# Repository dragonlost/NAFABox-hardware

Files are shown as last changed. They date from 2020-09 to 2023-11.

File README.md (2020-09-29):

# NAFABox-hardware   

__Version francaise :__    

Le but de ce projet, qui est née fin 2018, est de pouvoir proposer à tous des cartes électroniques plugables sur une carte Raspberry Pi (ou carte avec connecteur 40pins compatible) dédié aux astronomes amateurs.

Après 2 prototypes réalisés mais pas assez fonctionnel et compact à mon goût, l'idée fut de partir sur une achitecture modulaire stackable sur un Raspberry Pi.

Grâce à Kicad et ses possibilités 3D nous avons pu mener à bien ce projet.

Malheuresement, n'ayant pas de formation en électronique/design de PCB ou en réalisation mécanique, les réalisatons ne sont pas parfaite et ne respecte surement pas totalement les normes et caractéristique du domaine.

Ce projet est Open Source et donc j'invite toutes personnes voulant contribuer à sa réalisation à proposer un Pull Request/Issue ou à me contacter via mon Pseudo (le même que sur Github) sur Webastro ou sur le Discord : "Astro - FR".

__Attention :__ La plupart des modèles 3D présent dans de dossier __lib__ de chaque PCB sont issue du site https://grabcad.com/ et ne sont pas forcement tous OpenSource. Merci de respecter leurs droits de diffusion.

## Les différentes cartes :

Tout les schémas électronique sont disponible dans la Doc : https://github.com/dragonlost/NAFABox-hardware/tree/master/Doc/schema_pdf

### La carte de base :
(base_hat)     
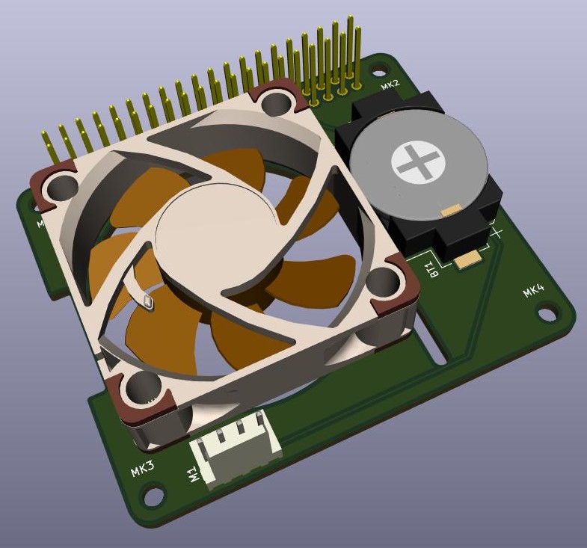
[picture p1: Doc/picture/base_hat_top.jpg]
base_hat_top
 
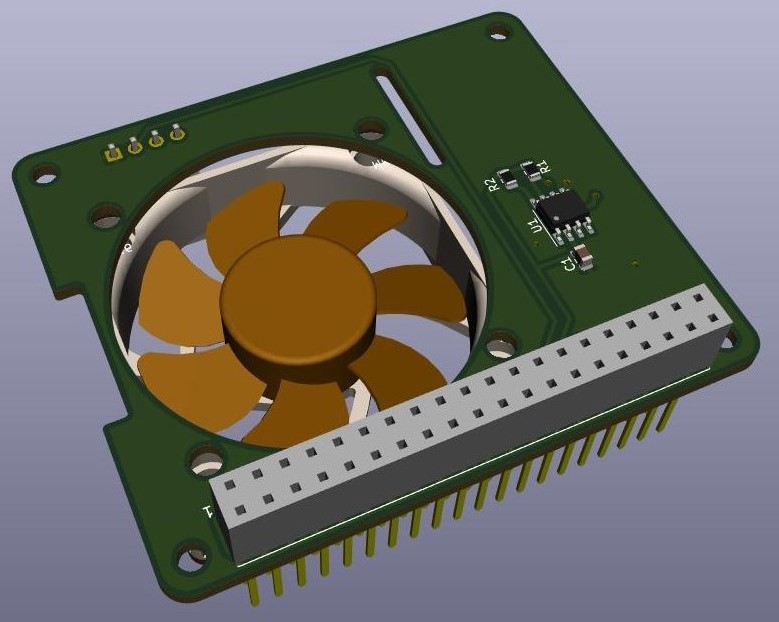
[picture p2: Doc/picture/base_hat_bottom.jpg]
base_hat_bottom
 

Cette carte contient principalement 2 parties : 
- un composant DS3231 en I2C afin de pouvoir obtenir une base de temps permanente pour le Raspberry Pi ainsi qu'un logement de pile pour un CR2032 remplacable
- un connecteur et emplacement pour un ventillateur de 30x30mm controlé en PWM par le Raspberry PI.  

### La carte d'alimentation :
(alim_hat)    
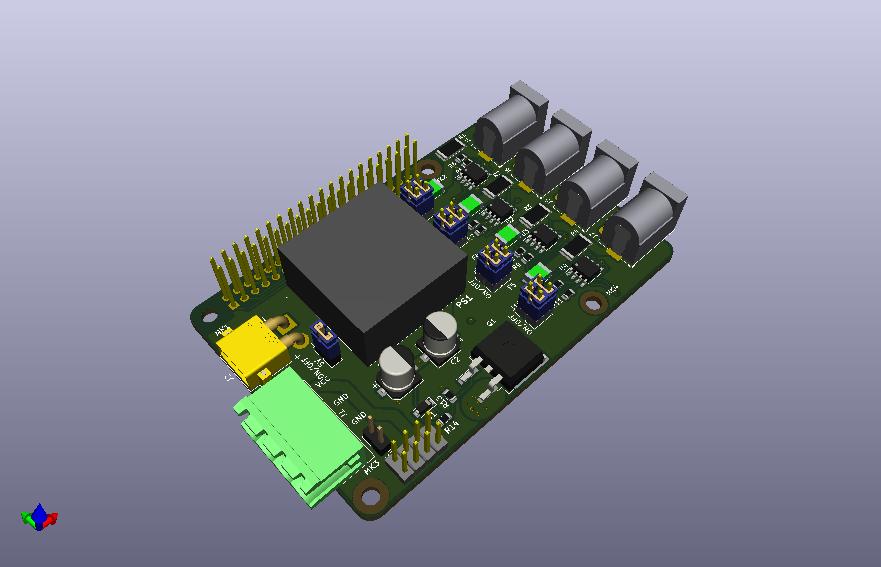
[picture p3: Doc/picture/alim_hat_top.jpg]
alim_hat_top
 
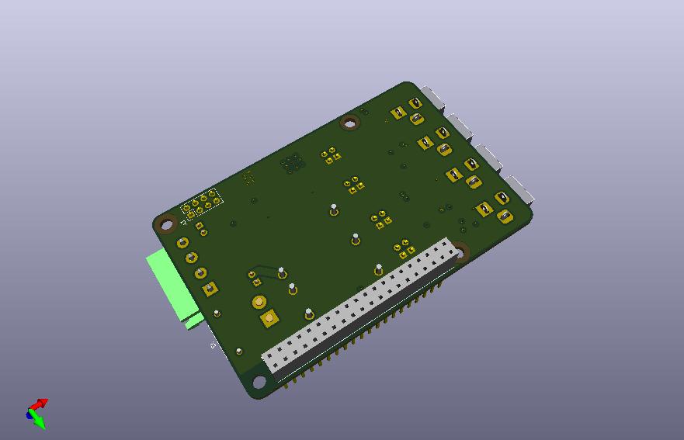
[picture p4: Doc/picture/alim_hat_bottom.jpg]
alim_hat_bottom
 

Elle contient :
- Une entrée d'alimentation Jack DC protégé contre l'inversion de courant.
- 4 sorties :
	- protégées par des fusibles rearmable PPTC ( polyswitch/polyfuse) de 5A
	- mesurer en courant et tension à l'aide d'INA219 en I2C ( un par sortie)
	- de tension identique à la tension d'entrée
- un connecteur 8 broches avec la tension d'entré (x2) et la masse (x4) ainsi qu'une autre tension (VCC) entrée via le bornier prevue à cette effet
- un convertisseur DC-DC stepdown PDQE15-Q24-S5-D isolé ( désactivable) pouvant délivré 3A en 5V relié au pins 5v du Raspberry Pi.
- de pin permettant de couper/connecter chaque sortie via un Jumper ou des interupteurs externe ou via la carte relais.

### La carte Relais/ Focuser
(relais_hat)
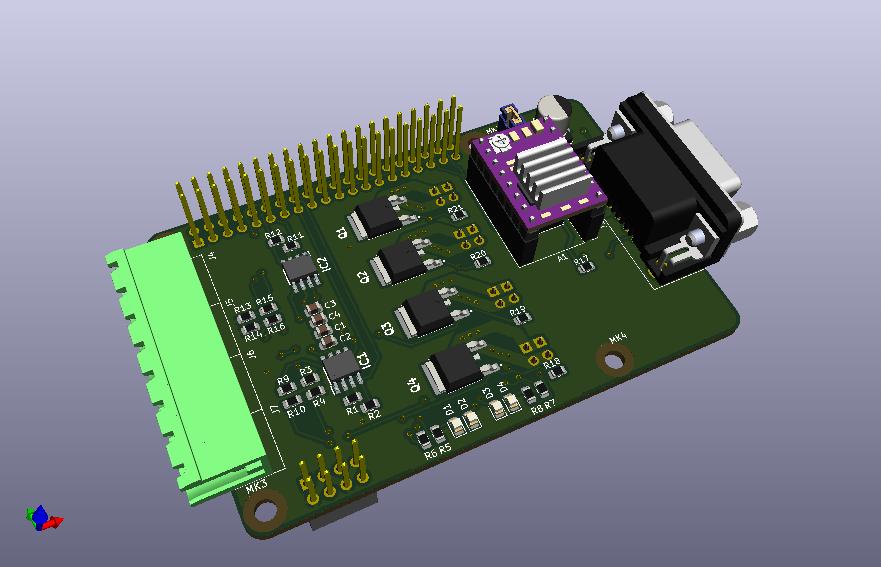
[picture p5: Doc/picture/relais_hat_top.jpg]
relais_hat_top
 
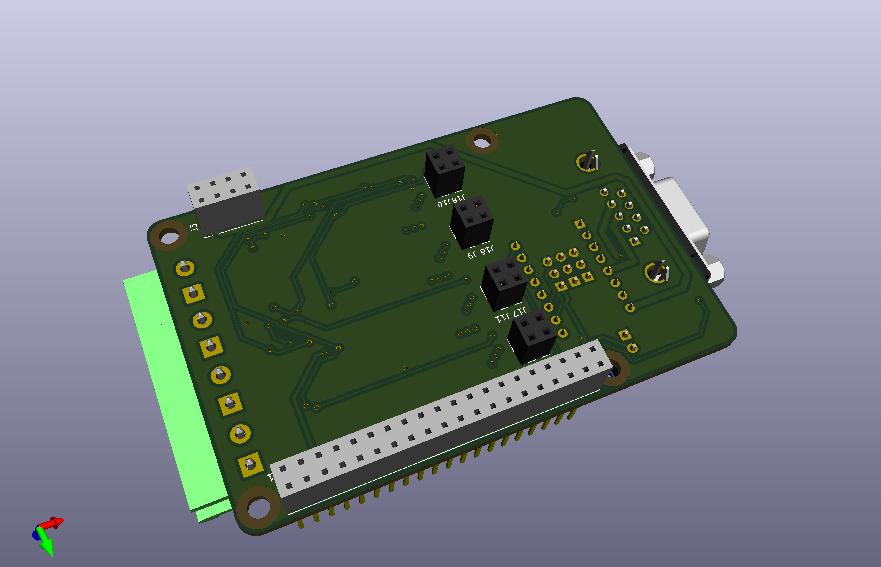
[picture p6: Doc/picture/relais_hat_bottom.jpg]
relais_hat_bottom
 

Elle contient :
- Un système de 4 relais :
	- 4 relais piloté via les GPIO de carte Raspberry PI (GPIO 17, 18, 22 et 23)
	- 4 leds indiquant l'état des relais (dans le même ordre D1, D2, D3, D4)
	- 4 sorties par pins plugable sur la carte d'alimentation pour piloter les 4 sorties.
	- 4 bornier pour piloter un système externe
- un connecteur 8 broches avec la tension d'entrée (x2) et la masse (x4) ainsi qu'une autre tension (VCC) entrée via le bornier de la carte d'alimentation
- Un système pour piloter un moteur pas à pas afin de réaliser la mise au point.
	- un emplacemnt pour driveur moteur au format pololu
	- un connecteur DB9 au format RoboFocus (A1=1, A2=2, B1=3, B2=4, GND=5)
	- un système de 3 jumper afin de piloter l'état des pins (libre, 3.3v, GND)
	- pilotage via les GPIO (STEP=GPIO25, DIR=GPIO27, SLP=GPIO24)
	- l'alimentation 12v via la connecteur 8 pins.

### La carte Resistance chauffante et GPS
(res_hat)
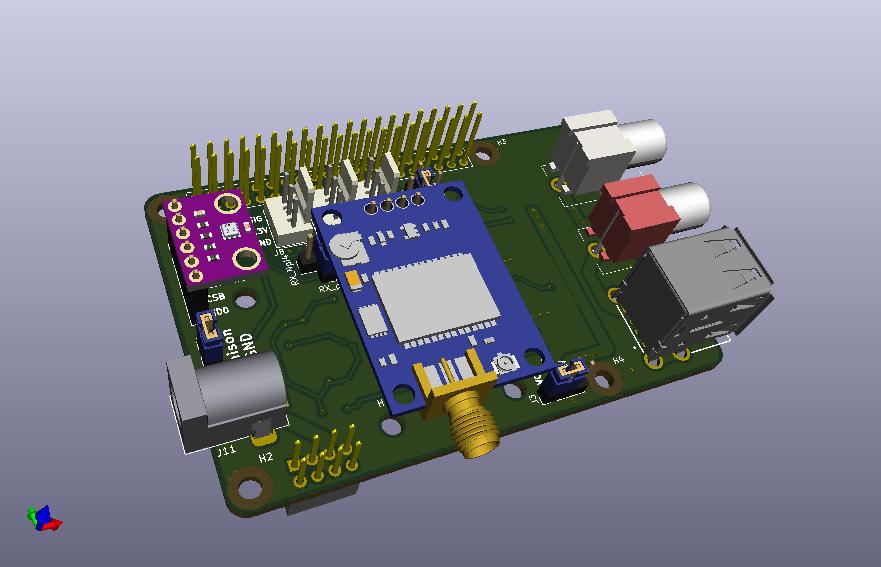
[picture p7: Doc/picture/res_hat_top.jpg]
res_hat_top
 
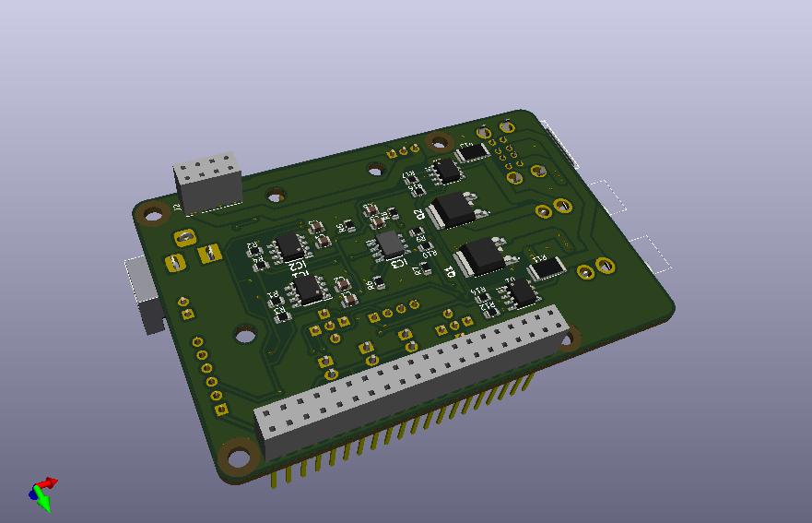
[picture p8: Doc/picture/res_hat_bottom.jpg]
res_hat_bottom
 

Elle contient :
- un connecteur 8 broches avec la tension d'entrée (x2) et la masse (x4) ainsi qu'une autre tension (VCC) entrée via le bornier de la carte d'alimentation
- un connecteur 4 pins pour connecteur une carte GPS UART (3.3v-RX-TX-GND) :
	- 2 trous de fixation mécanique
	- 2 systèmes de jumper afin d'inverser le TX/RX ou sélectioner d'autre pin TX-RX pour la carte Nanopi-M4 
- une entrée Jack DC connecter a la tension VCC.
- un système de résistance chauffante piloter par I2C :
	- 2 résistance possible, connectable via 2x USB (résistance en 5V par exemple) ou via 2x RCA.
	- chaque sortie est mesurée en tension et courant via des INA219 comme la carte d'alimentation
	- un connecteur pour une carte BME280 en i2C afin de calculer le point de rosé via la température et l'humidité local.
	- 2 connecteurs pour 2 capteurs D18B20 1wire (pin7 du RPI) afin de mesurer la température des résistances.
	- Chaque résistance est pilotable en puissance via 2 mofset FDD844L-F085
	- Il est posible via un jumper de sélectionner la tension d'alimentation des résistances entre l'entrée Jack de la carte d'alimentation (nomé: 12V) et l'entrée jack de la carte résistance ou du bornier de la carte d'alimentation (nomé: VCC)

## Le Boitier :

Le boitier destiné à accueillir les différentes cartes a été concue comme les cartes afin d'être modulaire. Chaque carte possède donc sa propre pièce.    
Les modèles 3D des cartes sont aussi disponibles afin de permettre à chacun de réaliser son propre boitier.

Elle a été aussi concu afin d'être facilement imprimable sur des imprimantes de capacité d'impression de 20x20x20.    

Les pièces ont été dessiné sous CATIA par __SUPAII__ puis publié en format STEP afin que chacun puisse les modifiés/convertir avec n'importe quel logiciel de CAO.    

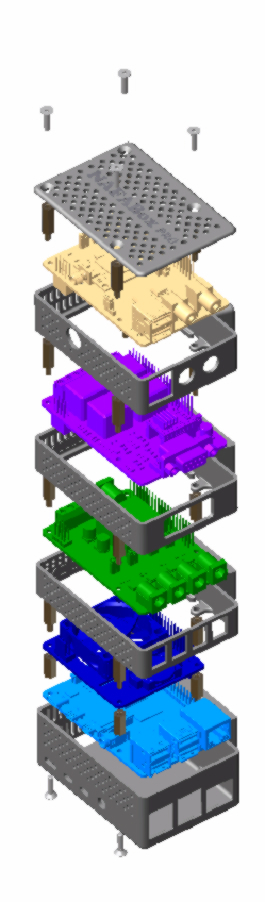
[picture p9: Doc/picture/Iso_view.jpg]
Iso_view

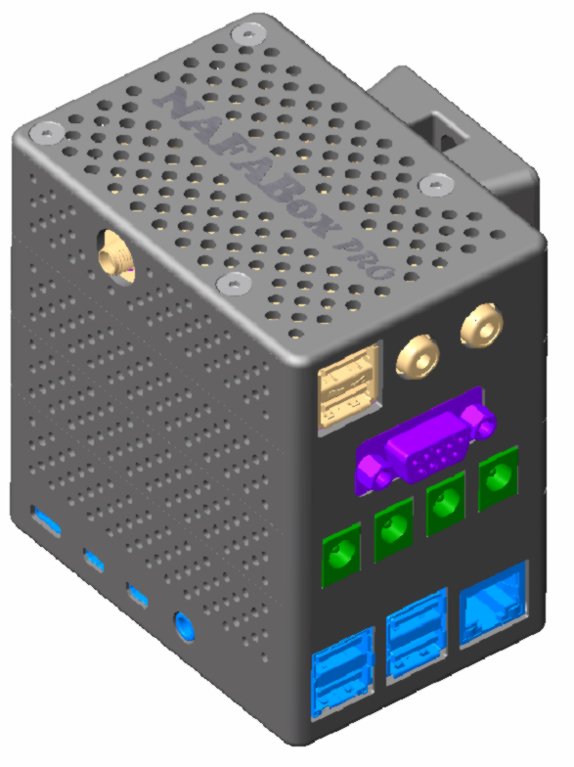
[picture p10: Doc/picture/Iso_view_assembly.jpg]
Iso_view_assembly


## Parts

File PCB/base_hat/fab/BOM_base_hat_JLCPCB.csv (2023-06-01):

Comment | Designator | Footprint | LCSC Part Number
RTC | U1 | SOIC-8 | C107410
10k ohm | R2,R1 | 805 | C17414
1 uF | C1 | 805 | C28323

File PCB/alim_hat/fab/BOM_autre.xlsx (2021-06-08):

BOM des composants non cablés par JLCPCB
ref-pcb | number | commentaire | fabriquant | ref fab | ref mouser | lien
PS1-15W | 0 | DC-DC for 5V | TDK-Lambda | CCG152405S | 967-CCG152405S | https://www.mouser.fr/ProductDetail/TDK-Lambda/CCG152405S?qs=LuYMPh7GGMTuVM%2FVwXHZSQ%3D%3D
PS1-15W-bis | 0 | DC-DC for 5V | TRACO Power | THL 15-2411WI | 495-THL15-2411WI | https://www.mouser.fr/ProductDetail/TRACO-Power/THL-15-2411WI?qs=vLWxofP3U2zTxW0y6%2FAPOg%3D%3D
PS1-20W | 0 | DC-DC for 5V | CUI Inc | PDQE20-Q24-S5-D | 490-PDQE20-Q24-S5-D | https://www.mouser.fr/ProductDetail/CUI-Inc/PDQE20-Q24-S5-D?qs=T3oQrply3y%2FtCzjhZ6U7qw%3D%3D
PS1-20W-bis | 0 | DC-DC for 5V | TRACO Power | THN 20-2411WI | 495-THN-20-2411WI | https://www.mouser.fr/ProductDetail/TRACO-Power/THN-20-2411WI?qs=ckJk83FOD0Ubd3fn7UBI5w%3D%3D
PS1-25W | 0 | DC-DC for 5V | TRACO Power | THL 25-1211 | 495-THL25-1211 | https://www.mouser.fr/ProductDetail/TRACO-Power/THL-25-1211?qs=ckJk83FOD0XJvwE%252BTzL8iQ%3D%3D
PS1-25W | 0 | DC-DC for 5V | XP Power | JWK2524S05 | 209-JWK2524S05 | https://www.mouser.fr/ProductDetail/XP-Power/JWK2524S05?qs=w%2Fv1CP2dgqp80DPt1kfK5Q%3D%3D
PS1-30W | 1 | DC-DC for 5V | TDK-Lambda | CCG302405S | 967-CCG302405S | https://www.mouser.fr/ProductDetail/TDK-Lambda/CCG302405S?qs=e%2Fel81Nv5izGPdnDEXuxbQ%3D%3D
PS1-30W-bis | 0 | DC-DC for 5V | CUI Inc | PDQ30-Q24-S5-D | 490-PDQ30-Q24-S5-D | https://www.mouser.fr/ProductDetail/CUI-Inc/PDQ30-Q24-S5-D?qs=ZGJ6LVh7YLDgi3Sd9Tq21g%3D%3D
PS1-30W-bis-bis | 0 | DC-DC for 5V | TRACO Power | THN 30-1211 | 495-THN-30-1211 | https://www.mouser.fr/ProductDetail/TRACO-Power/THN-30-1211?qs=ckJk83FOD0XjmIpWKdS%252Buw%3D%3D
J1 | 1 ou 2 | Bornier plugable x2 ou x4 | Aliexpress |  |  | https://fr.aliexpress.com/item/4000126734494.html
P1 | 1 | 2x20pin 15mm | Aliexpress |  |  | https://fr.aliexpress.com/item/4000970041759.html
J2 | 1 | XT30PW | Amass | XT30PW |  | https://fr.aliexpress.com/item/4001122646873.html
J4,J5,J6,J7 | 4 | DC Jack 5,5x2,1/2,5 | Aliexpress |  |  | https://fr.aliexpress.com/item/4000034340966.html
J3,J8,J9,J10,J11,J13,J14,J15,J16 | 2 barrette | longeur 15mm | Aliexpress |  |  | https://fr.aliexpress.com/item/32896293058.html

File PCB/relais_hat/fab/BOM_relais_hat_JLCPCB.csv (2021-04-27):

Comment | Designator | Footprint | LCSC Part Number
UCC27324D | IC1, IC2, | SOIC-8 | C46427
100uF | C5 | Cp 6.3x7.7 | C134792
LED | D1,D2,D3,D4 | LED 0805 | C84256
0.1uF | C1, C3, | C 0805 | C49678
1uF | C2, C4, | C 0805 | C28323
FDD8447L-F085 | Q1, Q2, Q3, Q4, | TO-252-2 | C154314
10k ohm | R1, R2, R3, R4, R11, R12, R13, R14, R18, R19, R20, R21 | R 0805 | C17414
470 ohm | R5,R6,R7,R8 | R 0805 | C17710
100 ohm | R9, R10, R15, R16, | R 0805 | C17408
4.7k | R17 | R_0805 | C17673

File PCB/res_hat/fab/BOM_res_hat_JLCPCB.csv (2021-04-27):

Comment | Designator | Footprint | LCSC Part Number
10uF | C1,C3 | C_0805 | C15850
0.1uF | C2,C4,C5 | C_0805 | C49678
1uF | C6 | C_0805 | C28323
UCC27324D | IC3 | SOIC-8 | C46427
0.02 1W | R11,R13 | R_2512 | C127705
4.7k | R15 | R_0805 | C17673
10k | R1,R2,R3,R4,R5,R6,R7,R8,R12,R14,R16,R17 | R_0805 | C17414
100ohm | R9,R10 | R_0805 | C17408
INA219AxD | U1,U2 | SOIC-8 | C138706
MOSFET | Q1,Q2 | TO-252-2 | C154314

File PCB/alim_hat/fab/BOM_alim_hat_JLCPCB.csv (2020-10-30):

Comment | Designator | Footprint | LCSC Part Number
100uF | C1,C2 | CAPA 660X800 | C134792
MM1Z15 | D1 | SOD-123 | C86235
470k | R14 | R 0805 | C17709
1k | R13 | R 0805 | C17513
10k | R5,R6,R7,R8,R9,R10,R11,R12 | R 0805 | C17414
INA219AxD | U1,U2,U3,U4 | SOIC-8 | C138706
0,02 1W | R1,R2,R3,R4 | R 2512 | C127705
IRFS7530 | Q1 | TO-263-2 | C500544
SMD1812P300SLR/24 | F2,F3,F4,F5 | Fuse 1812 | C495359

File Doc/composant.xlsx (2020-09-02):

Commentaire | Ref constructeur | Ref JLCPCB | lien
INA219 | INA219AIDR | C138706 | https://www.mouser.fr/ProductDetail/Texas-Instruments/INA219AIDR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
Fuse 5A | 2920L500/16MR | C207091 | https://www.mouser.fr/ProductDetail/Littelfuse/2920L500-16MR
Condo 100uF | EEE-FTH101XAP | C311622 | https://www.mouser.fr/ProductDetail/Panasonic/EEE-FTH101XAP?qs=CMJjuEs1%252BuH92gzZHu330A%3D%3D
Boitier pile | 1060 |  | https://www.mouser.fr/ProductDetail/Keystone-Electronics/1060
Fuse protection sens courant | 1206L020YR | C151162 | https://www.mouser.fr/ProductDetail/Littelfuse/1206L020YR?qs=PWhpLWeW8we48TZL2V8mHQ%3D%3D
Diode protection sens | B140HW-7 | C134429 | https://www.mouser.fr/ProductDetail/Diodes-Incorporated/B140HW-7?qs=oVWkMaT70e5se8Oc7Nomfg%3D%3D
DAC I2C resistance | MCP4725A0T-E/CHVAO | C144198 | https://www.mouser.fr/ProductDetail/Microchip-Technology/MCP4725A0T-E-CHVAO
MOFSET resistance | FDD8447L-F085 | C99591 | https://www.mouser.fr/ProductDetail/ON-Semiconductor-Fairchild/FDD8447L-F085
Gate driver resistance | UCC27324DR | C46427 | https://www.mouser.fr/ProductDetail/Texas-Instruments/UCC27324DR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
diode relay | 1N4148W-7-F | C60580 | https://www.mouser.fr/ProductDetail/Diodes-Incorporated/1N4148W-7-F?qs=LHX0FizJzg7Ae9ZM8LTAWw%3D%3D
Inspiration circuit resistance | Single MOS Switch |  | https://fr.aliexpress.com/item/2005868831.html
capteur humidité + temp I2C | GY-BME280-3,3V |  | https://www.amazon.fr/Peanutaor-Pression-atmosph%C3%A9rique-GY-BME280-3-3V-pr%C3%A9cision/dp/B07W8NCG5K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
RTC | DS3231MZ+ | C107410 | https://www.mouser.fr/ProductDetail/Maxim-Integrated/DS3231MZ%2b
Convertisseur 5V | PDQE15-Q24-S5-D |  | https://www.mouser.fr/ProductDetail/CUI-Inc/PDQE15-Q24-S5-D
Port USB Double | 61400826021 |  | https://www.mouser.fr/ProductDetail/Wurth-Elektronik/61400826021
Connecteur resistance | KLPX-0848A-2-O |  | https://www.mouser.fr/ProductDetail/Kycon/KLPX-0848A-2-O
Connecteur resistance 2 | RCJ-042 |  | https://www.mouser.fr/ProductDetail/CUI-Devices/RCJ-042?qs=sGAEpiMZZMs8jstQXqv0yZyD0iSSiRNa1CWAXH4j62w%3D
Led relais | HSMH-C150 | C375461 | https://www.mouser.fr/ProductDetail/Broadcom-Avago/HSMH-C150
relais | HLS8L-DC3V-S-C |  | https://fr.aliexpress.com/item/32852914730.html
transistor relais | MMSS8050-L-TP | C2146 | https://www.mouser.fr/ProductDetail/Micro-Commercial-Components-MCC/MMSS8050-L-TP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
convertisseur relay | XC6206P302MR-G | C5446 | https://www.mouser.fr/ProductDetail/Torex-Semiconductor/XC6206P302MR-G?qs=AsjdqWjXhJ%2FCPGHa4B8pZA%3D%3D
DAC I2C resistance 2 | LTC2633AHTS8-LZ12#TRMPBF |  | https://www.mouser.fr/ProductDetail/Analog-Devices/LTC2633AHTS8-LZ12TRMPBF?qs=hVkxg5c3xu86gDwda4HjLQ%3D%3D
carte relais | Grove Relay |  | https://wiki.seeedstudio.com/Grove-Relay/

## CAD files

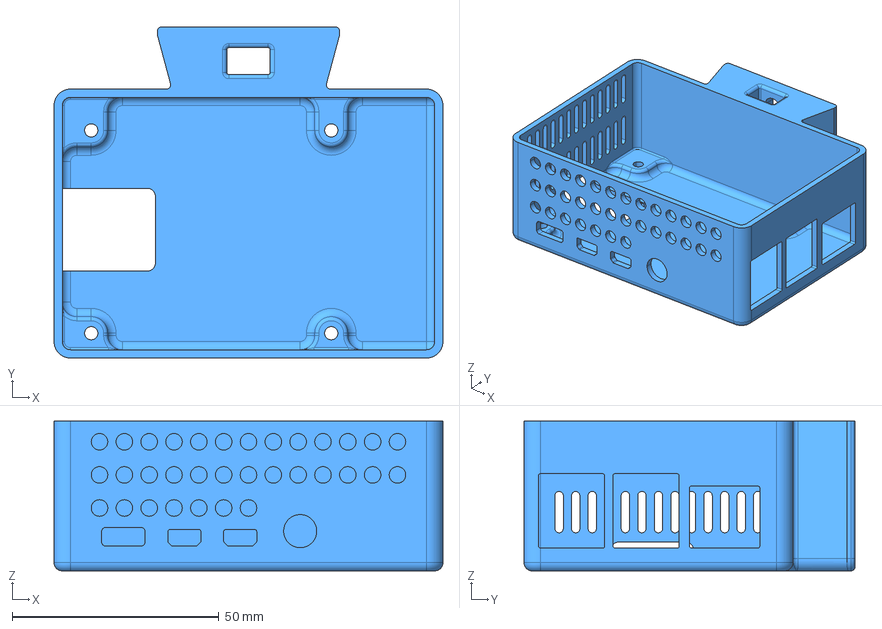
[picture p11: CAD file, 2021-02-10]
Box/Box_3D_model/Carter RPI4.stp
94.0 x 80.0 x 36.2 mm

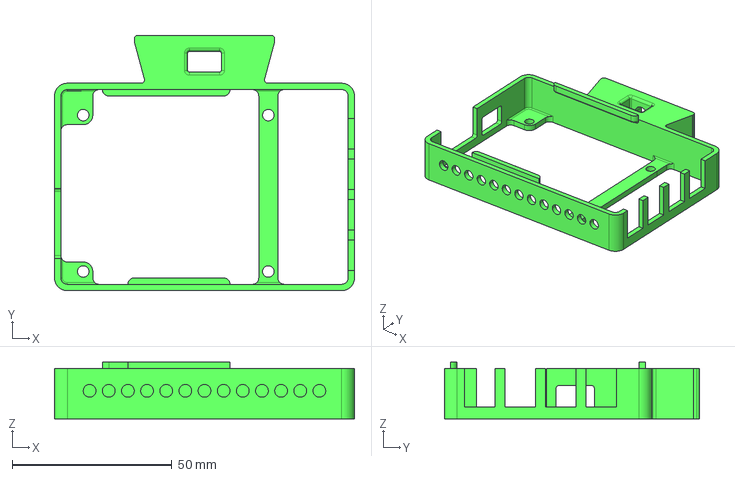
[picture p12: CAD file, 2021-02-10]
Box/Box_3D_model/Carter Power.stp
94.0 x 80.0 x 17.8 mm

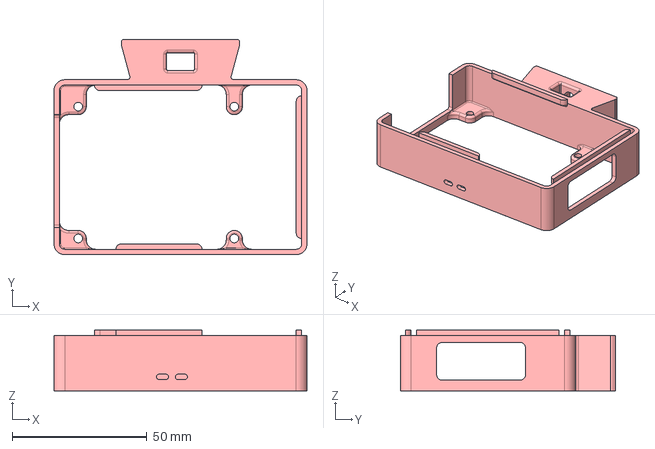
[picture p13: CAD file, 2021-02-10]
Box/Box_3D_model/Carter Relai-Focus.stp
94.0 x 80.0 x 22.6 mm

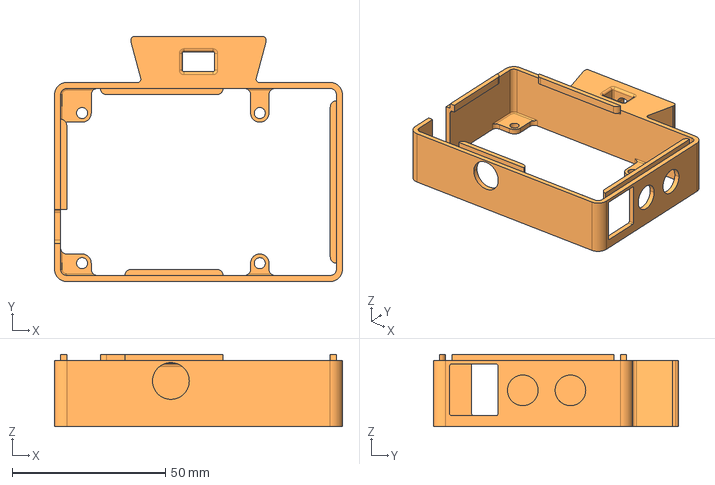
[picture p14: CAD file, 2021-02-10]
Box/Box_3D_model/Carter ReS.stp
94.0 x 80.0 x 23.6 mm

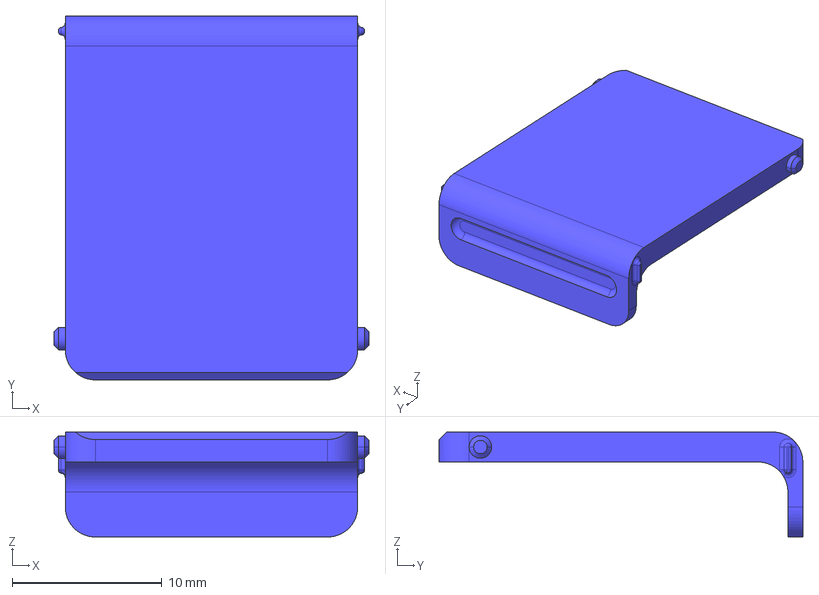
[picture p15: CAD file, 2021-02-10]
Box/Box_3D_model/Couvercle SD.stp
21.0 x 24.2 x 7.00 mm

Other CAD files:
Box/Box_3D_model/Carter Power.stl
Box/Box_3D_model/Carter ReS.stl
Box/Box_3D_model/Carter Relai-Focus.stl
Box/Box_3D_model/Couvercle SD.stl

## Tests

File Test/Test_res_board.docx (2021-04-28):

NAFAbox “Res_hat” board test procedure

Abstract :

This document summarizes the specifications of the “Res_hat” board of NAFAbox, present the tests procedures of these specifications, and expose the results.

| Date | Signature
Prepared by : - Guitton Thomas | 13/04/2021
Approved by :

Modification History
Ed. | Rev. | Date | Modifications | Visa
1 | 0

# 1 Glossaries

CAO GND MOSFET PCB PCBA | | Conception Assisté par Ordinateur (computer assisted conception) Ground Metal Oxide Semiconductor Field Effect Transistor Printed Circuit Board Printed Circuit Board Assembly

# 2 Document Presentation

This document is training for electronic board test of NAFAbox project. It is a summary of the specification of the board, with associated tests to verify these specifications, and expose the result of these tests and concluded that the card is functioning properly or not.

# 3 Tests

## 3.1 Test 1: Visual check

Procedure | Results | Comments
Check solder: any pin without solder? No solder bridge? | Missing solder on 5 pins of the 40 pins header. Non-compliant welding. => Validated. | No impacts since the 5 GPIOs are not used (our case). No impact, potential bridge between GND and isolation.
Check components’ polarity. | No polarity issues. => Validated.
Check holes: isolation, metallicity, Via. | No isolation issues. No metallicity issues. No Via issues. H5 mounting hole (BME280 board’s fixation) too small. => Validated. | Modified on PCB. No big impact since connector 01x06 ensure fixation.

## 3.2 Test 2: 12V equipotential

Procedure | Results | Comments
Connect the board with the powered “alim_hat” board. Check all 12V pins. 12V should be observed. | 12.04V observed for each 12V pins. => Validated.

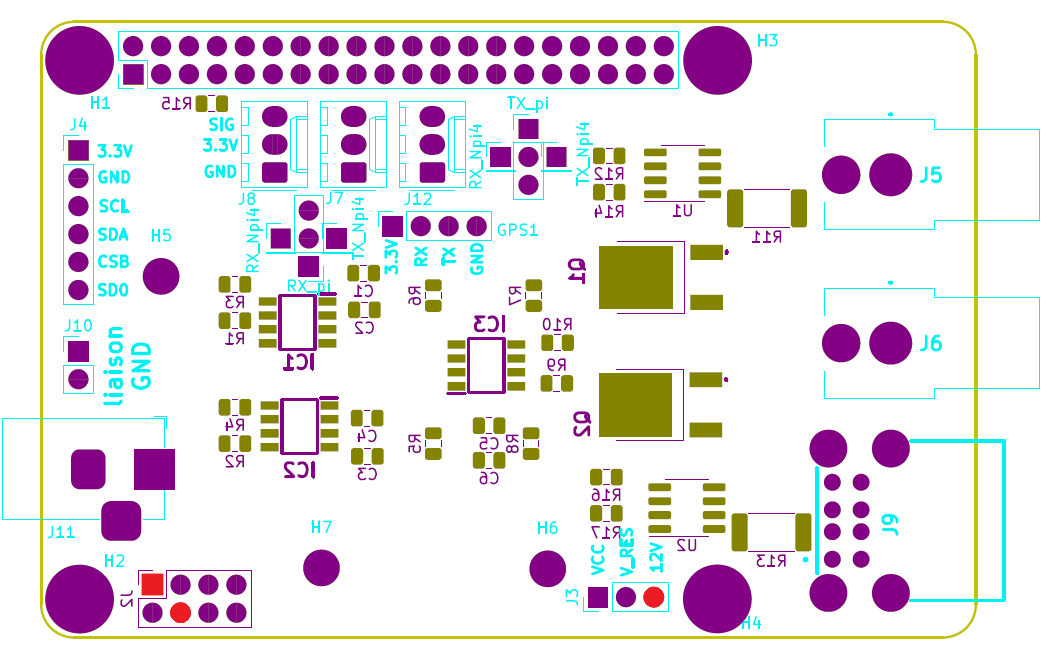
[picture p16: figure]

12V pins map

## 3.3 Test 3: VCC equipotential

Procedure | Results | Comments
Supply the board with VCC on J11 connector. Check all VCC pins. VCC voltage should be observed. | VCC was chosen to be 5V. 5.01V observed for each VCC pins. => Validated.

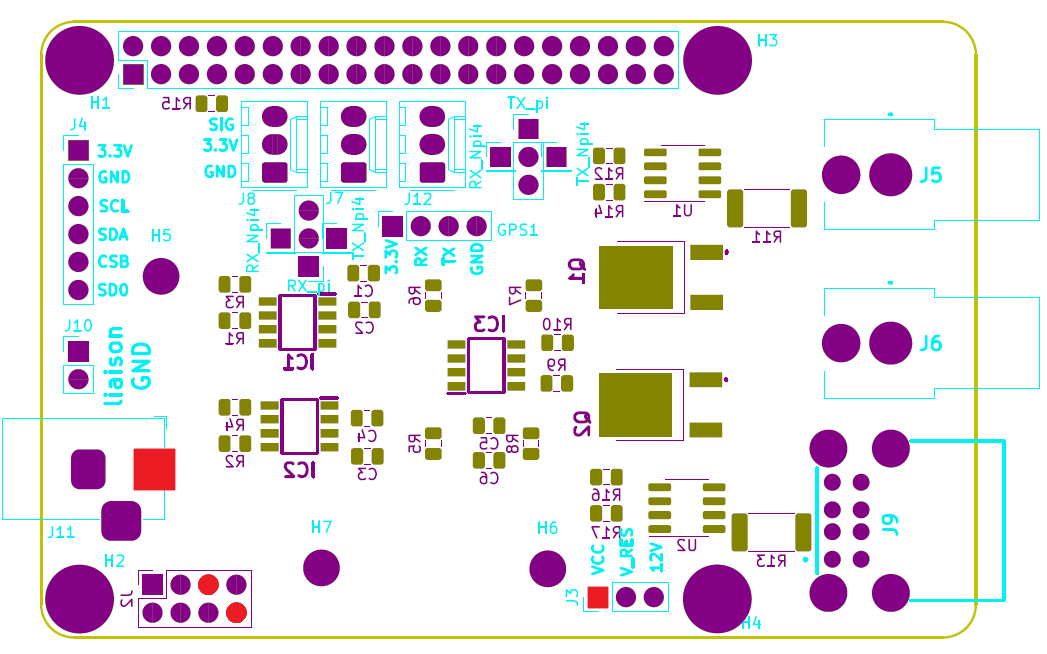
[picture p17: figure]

VCC pins map

## 3.4 Test 4: V_RES equipotential

Procedure | Results | Comments
Open J3 jumper. No voltage should be observed on V_RES pins. | 0.0004V observed for V_RES pins. => Validated.
Connect the board with the powered “alim_hat” board. Close J3 jumper with 12V. 12V should be observed on V_RES pins. | 12.04V observed for each V_RES pins. => Validated.
Supply the board with VCC on J11 connector. Close J3 jumper with VCC. VCC voltage should be observed on V_RES pins. | VCC was chosen to be 5V. 5.01V observed for each V_RES pins. => Validated.

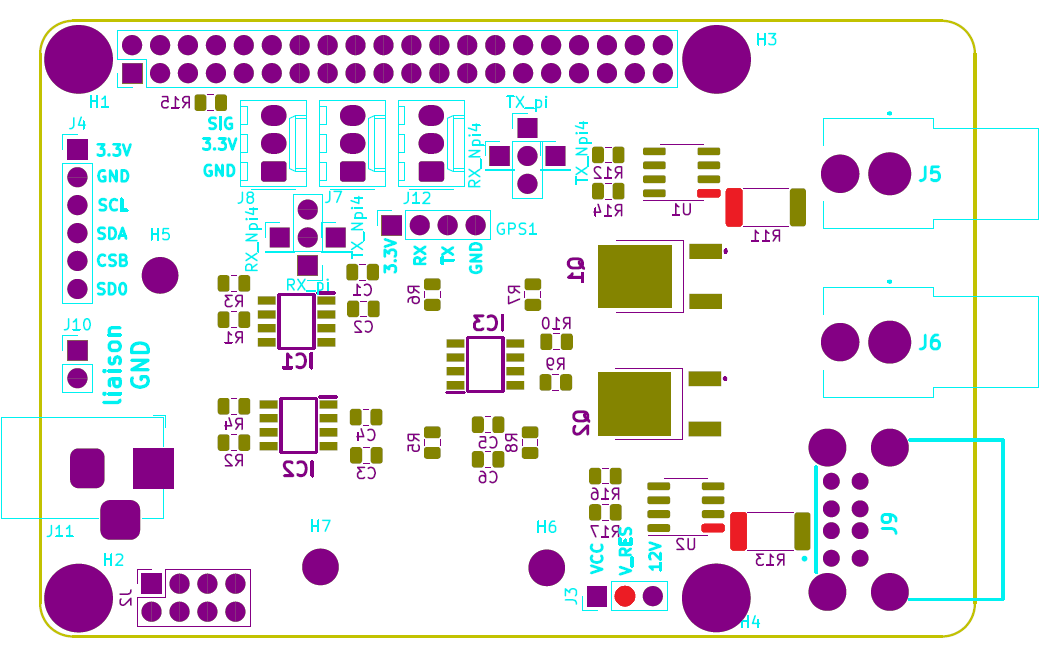
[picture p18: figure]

V_RES pins map

## 3.5 Test 5: 5V equipotential

Procedure | Results | Comments
Connect the board with the powered “alim_hat” board. Check all 5V pins. 5V should be observed. | 5.01V observed for each 5V pins. => Validated.

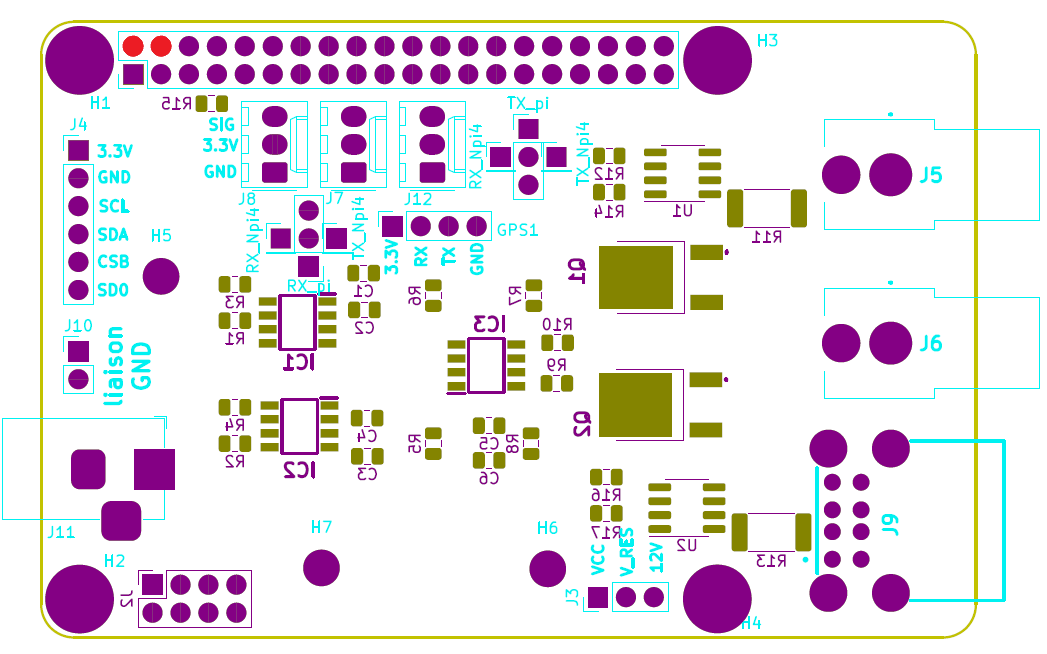
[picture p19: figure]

5V pins map

## 3.6 Test 6: 3.3V equipotential

Procedure | Results | Comments
Connect the board with the Raspberry pi 4. Check all 3.3V pins. 3.3V should be observed. | 3.288V observed for each 3.3V pins. => Validated.

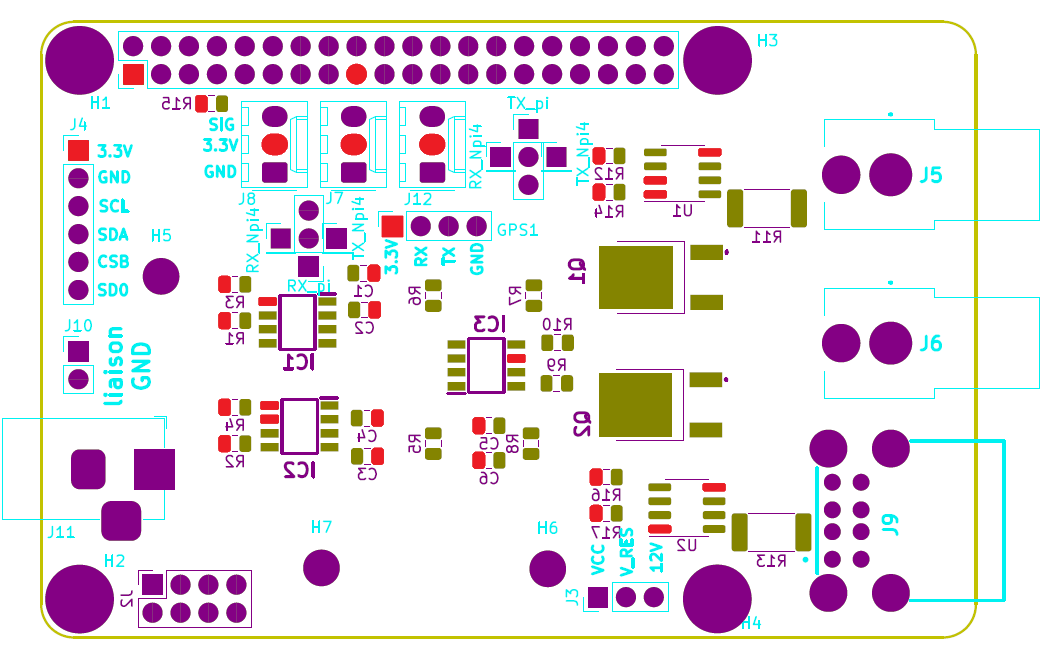
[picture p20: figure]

3.3V pins map

## 3.7 Test 7: GND equipotential

Procedure | Results | Comments
Connect the board with the Raspberry pi 4. Close “liaison GND” jumper. Check all GND pins. | Continuity ensured between GND pins. Continuity ensured between GND_Rpi pins. Continuity ensured between GND pins and GND_Rpi pins with “Liaison GND” jumper Closed. => Validated.

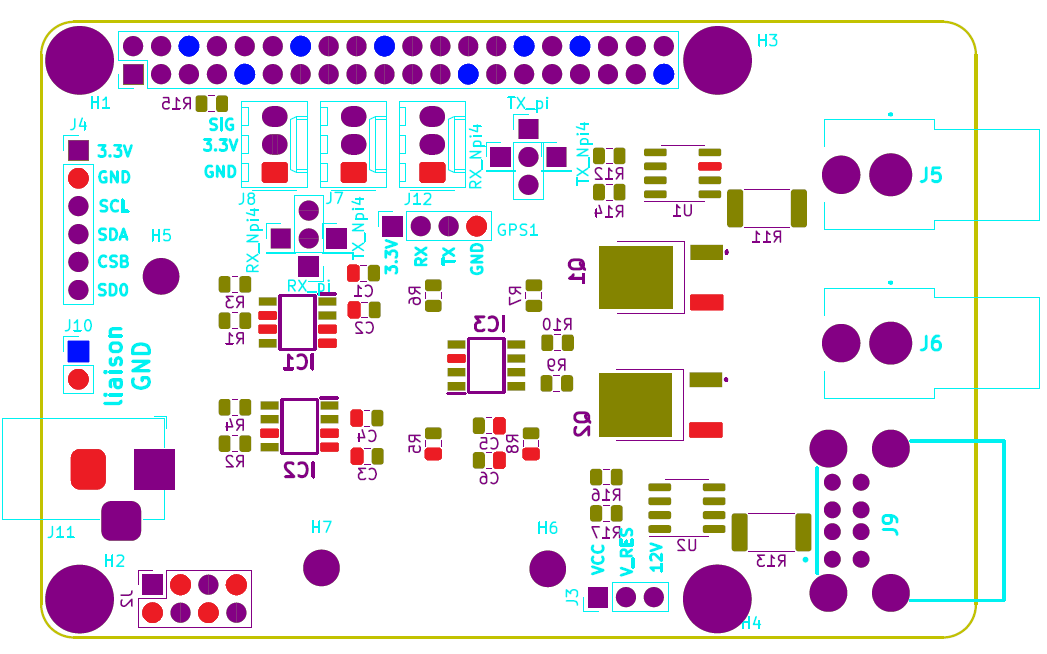
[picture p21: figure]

GND pins and GND_Rpi pins map

## 3.8 Test 8: UART communication

Procedure | Results | Comments
Connect the board with the Raspberry pi 4. Open both UART cross jumpers. Check continuity for this configuration. No sound response should be heard. | No sound response heard. => Validated.
Close both UART cross jumpers with the configuration: RX_pi/RX and TX_pi/TX. Check continuity for this configuration. A sound response should be heard. | Sound response heard. Continuity is ensured between RX_pi/RX and TX_pi/TX. => Validated. | Two continuity must be checked (RX_pi/RX and TX_pi/TX).
Close both UART cross jumpers with the configuration: TX_pi/RX and RX_pi/TX. Check continuity for this configuration. A sound response should be heard. | Sound response heard. Continuity is ensured between TX_pi/RX and RX_pi/TX. => Validated. | Two continuity must be checked (TX_pi/RX and RX_pi/TX).
Close both UART cross jumpers with the configuration: RX_Npi4/RX and TX_Npi4/TX. Check continuity for this configuration. A sound response should be heard. | Sound response heard. Continuity is ensured between RX_Npi4/RX and TX_Npi4/TX. => Validated. | Two continuity must be checked (RX_Npi4/RX and TX_Npi4/TX).
Close both UART cross jumpers with the configuration: TX_Npi4/RX and RX_Npi4/TX. Check continuity for this configuration. A sound response should be heard. | Sound response heard. Continuity is ensured between TX_Npi4/RX and RX_Npi4/TX. => Validated. | Two continuity must be checked (TX_Npi4/RX and RX_Npi4/TX).
With one of these configurations, establish a communication. Communications should be observed between GPS and Raspberry pi 4. | No communication establish with GPS. => Not validated.

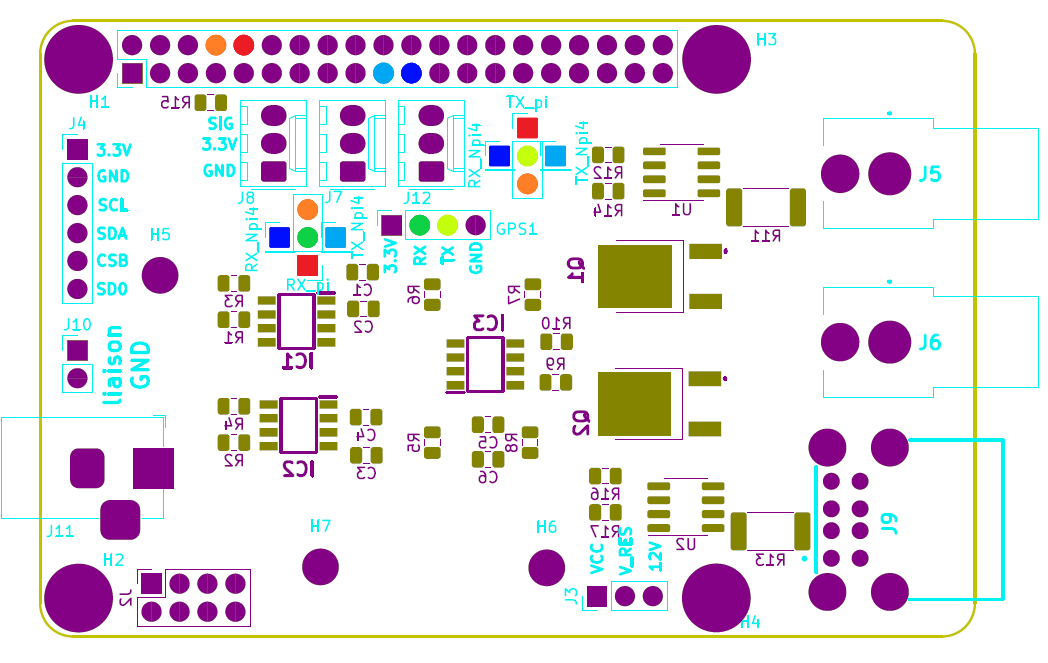
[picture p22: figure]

RX, TX, RX_pi, TX_pi, RX_Npi4 and TX_Npi4 pins map

## 3.9 Test 9: MOSFETs FDD844L-F085

Procedure | Results | Comments
For each MOSFET (Q1 and Q2): Check continuity between MOSFET source pin and MOSFET drain pin. No sound response should be heard. | No sound response heard. MOSFETs are in blocking mode. => Validated. | IC1 command PWM for Q1. IC2 command PWM for Q2. IC1 address : 0101000 IC2 address : 0101010
Connect the board with the Raspberry pi 4. Supply V_RES = 5V. With a PWM ratio of 25%. Check the current through the MOSFET. I_(25%) =x_1 A > 0A should be observed. | 0.36A observed through Q1 MOSFET. 0.35A observed through Q2 MOSFET. => Validated.
With a PWM ratio of 50%. Check the current through the MOSFET. I_(50%) = x_2 A > x_1 A should be observed. | 0.83A observed through Q1 MOSFET. 0.81A observed through Q2 MOSFET. => Validated.
With a PWM ratio of 75%. Check the current through the MOSFET. I_(75%) = x_3 A > x_2 A should be observed. | 1.29A observed through Q1 MOSFET. 1.27A observed through Q2 MOSFET. => Validated.
With a PWM ratio of 100%. Check the current through the MOSFET. I_(100%) = x_4 A > x_3 A should be observed. | 1.87A observed through Q1 MOSFET. 1.84A observed through Q2 MOSFET. => Validated. | x_4 must be the current request by the heating resistor, x_4 =2.5A in our case. A current loss is observed (cables junction is one of the factors). The operating logic is respected, current increase through the MOSFET when PWM increase.

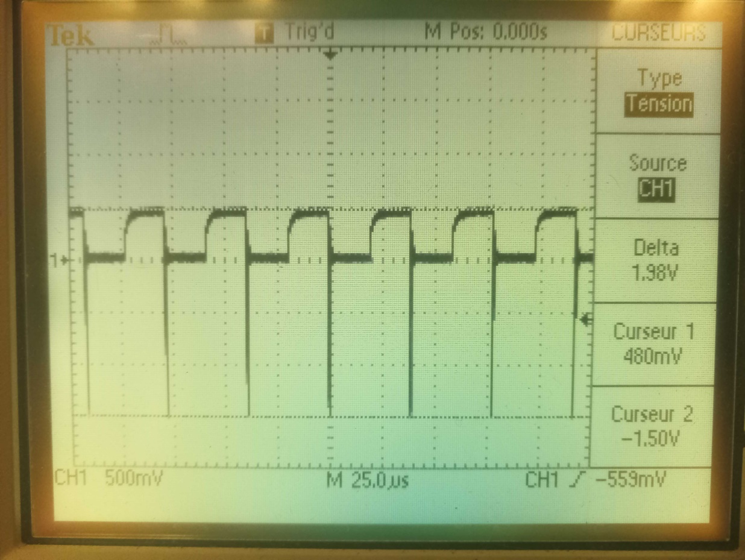
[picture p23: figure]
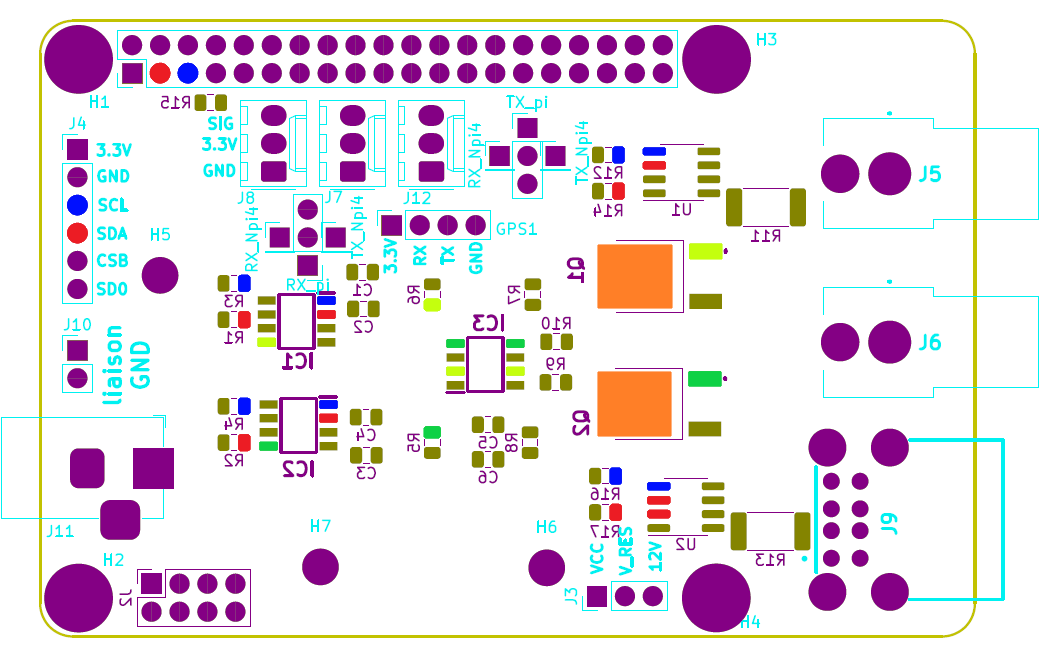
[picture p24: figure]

MOSFET drain

MOSFET drain

SDA, SCL, PWM1, PWM2 pins map

## 3.10 Test 10: USB resistor

Procedure | Results | Comments
Connect the board with the Raspberry pi 4. Connect a heating resistor to USB connector. For each PWM signal tested with MOSFETs, check the current through the USB connector. Current should be identical to the MOSFETs ones. | Same current than MOSFETs one observed for USB. => Validated.

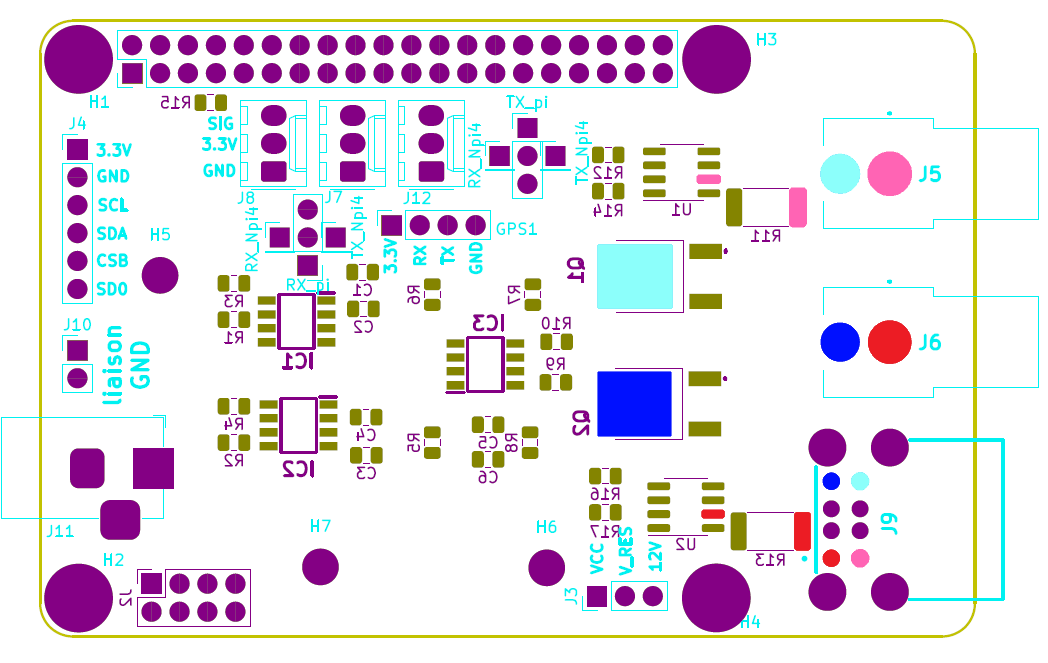
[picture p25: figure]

V+ pins, V- pins and V+ pins and V- pins map

## 3.11 Test 11: RCA resistor

Procedure | Results | Comments
Check continuity between RCA and USB pins. A sound response should be heard. | Sound response heard. Continuity is ensured between RCA and USB. => Validated. | RCA and USB are equivalent. Because continuity is ensured, USB test results cover RCA test results. Continuity observed between V+ pins and V+ pins, no impact.

## 3.12 Test 12: BME280 board communication

Procedure | Results | Comments
Connect the board with the Raspberry pi 4. Request for local temperature, and humidity with I2C. Local temperature in °C and humidity in % and the calculated dew point should be returned. | Communication establish with BME280 board. Return 24.08°C, 20.98% humidity and dew point = 0.366. Consistent values. => Validated. | BME280 address : 1110110


SDA pins and SCL pins map

## 3.13 Test 13: INA219 communication

Procedure | Results | Comments
Connect the board with the Raspberry pi 4. For each INA219 (U1 and U2): With a heating resistor connected to the USB connector, request for current and voltage in I2C. V_RES and the heating resistor current should be returned. | INA219 in short circuit since voltage inversion have been applied and ESD chocks have been introduced. Tests cannot be performed. => Not validated. | U1 address : 1000101 U2 address : 1000110 INA219 initially not in short circuit. Manipulation error had create the short circuit.

SDA pins and SCL pins map

## 3.14 Test 14: D18B20 sensors communication

Procedure | Results | Comments
Connect the board with the Raspberry pi 4. Request for resistor temperature. A temperature in °C should be returned. | 1-wire detected. Multiple sensors with different address identified. 23°C return for room temperature and 31°C return for hand temperature. => Validated.


1-Wire pins map

# 4 Error report

## 4.1 Functionality

- No communication with GPS board.
- INA219 in short circuit since voltage inversion have been applied and ESD chocks have been introduced.

## 4.2 CAO/Fabrication

- Missing labels for IC1, IC2, IC3, Q1 and Q2 on PCBA (corrected on PCB).
- Fixation hole of BME280 board too small on PCBA (corrected on PCB).
- TX_pi label on cross jumper is not corresponding to associate pins on PCBA (corrected on PCB).

Ionospheric and Gamma-ray Observations Satellite Ref. XXX-YY-NN Edition 1 Date xx-xx-xx Revision 0 Date xx-xx-xx

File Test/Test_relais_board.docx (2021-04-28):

NAFAbox “Relais_hat” board test procedure

Abstract :

This document summarizes the specifications of the “Relais_hat” board of NAFAbox, present the tests procedures of these specifications, and expose the results.

| Date | Signature
Prepared by : - Guitton Thomas | 13/04/2021
Approved by :

Modification History
Ed. | Rev. | Date | Modifications | Visa
1 | 0

# 1 Glossaries

CAO GND LED MOSFET | | Conception Assisté par Ordinateur (computer assisted conception) Ground Light-Emitting Diode Metal Oxide Semiconductor Field Effect Transistor

# 2 Document Presentation

This document is training for electronic board test of NAFAbox project. It is a summary of the specification of the board, with associated tests to verify these specifications, and expose the result of these tests and concluded that the card is functioning properly or not.

# 3 Tests

## 3.1 Test 1: Visual check

Procedure | Results | Comments
Check solder: any pin without solder? No solder bridge? | No solder issues. => Validated.
Check components’ polarity. | No polarity issues. => Validated.
Check holes: isolation, metallicity, Via. | No isolation issues. No metallicity issues. No Via issues. => Validated.

## 3.2 Test 2: 12V equipotential

Procedure | Results | Comments
Connect the board with the powered “alim_hat” board. Check all 12V pins. 12V should be observed. | 12.06V observed for each 12V pins. => Validated.


12V pins map

## 3.3 Test 3: VCC equipotential

Procedure | Results | Comments
Connect the board with the powered “alim_hat” board. Check all VCC pins. VCC voltage should be observed. | VCC was chosen to be 5V. 5.01V observed for each VCC pins. => Validated.


VCC pins map

## 3.4 Test 4: 5V equipotential

Procedure | Results | Comments
Connect the board with the powered “alim_hat” board. Check all 5V pins. 5V should be observed. | 5.01V observed for each 5V pins. => Validated.


5V pins map

## 3.5 Test 5: 3.3V equipotential

Procedure | Results | Comments
Connect the board with the Raspberry pi 4. Check all 3.3V pins. 3.3V should be observed. | 3.297V observed for each 3.3V pins. => Validated.


3.3V pins map

## 3.6 Test 6: GND equipotential

Procedure | Results | Comments
Connect the board with the Raspberry pi 4. Close J14 jumper. Check all GND pins. | Continuity ensured between GND pins. Continuity ensured between GND_Rpi pins. Continuity ensured between GND pins and GND_Rpi pins with J14 jumper Closed. => Validated.


GND pins and GND_Rpi pins map

## 3.7 Test 7: MOSFETs

Procedure | Results | Comments
Connect the board with the Raspberry pi 4. For each MOSFET (Q1, Q2, Q3 and Q4): Check continuity between MOSFET and associated Connector. | Continuity 1st test: contradiction. Three MOSFETs are in passing mode (not supposed to be in) and after double check only Q3 still in passing mode (changing mode not commanded → contradiction). => Redo the test later with another multi-meter. Continuity 2nd test: confirmation. Continuity ensured for Q1, Q2 and Q4. Q3 MOSFET is in passing mode. => Not validated. Continuity 3rd test: validation. Continuity ensured for Q1, Q2, Q3 and Q4. Q3 MOSFET is in blocking mode. => Ensure right functioning with the other tests. | Conn J4 associated with Q3. Conn J5 associated with Q4. Conn J6 associated with Q1. Conn J7 associated with Q2. Q3 MOSFET is faulty. Return to normal for all MOSFETs.
With the MOSFET into blocking mode, supply 12V on drain pins. Check voltage on source pins. No voltage should be observed. | 0V observed for each source pins of each MOSFET. => Validated.
Command the MOSFET into passing mode with the associated GPIO. 12V should be observed on source pins. | 2V observed for each source pins of each MOSFET. => Not validated. Look at “Error report” for explanations. | GPIO22 control Q1 MOSFET. GPIO23 control Q2 MOSFET. GPIO17 control Q3 MOSFET. GPIO18 control Q4 MOSFET.
When MOSFET is in passing mode, the associated LED should be turned on. | LEDs turned on when commands are activated. => Validated. | LED D1 associated with Q3. LED D2 associated with Q4. LED D3 associated with Q1. LED D4 associated with Q2. LEDs do not inform that the MOSFET is in passing mode but inform that the command to passing mode is active.


MOSFET drain

MOSFET drain

MOSFET drain

MOSFET drain

GPIO 17, GPIO 18, GPIO 22, GPIO 23, MOSFET drain and MOSFET source pins map

## 3.8 Test 8: Motor driver

Procedure | Results | Comments
Connect the board with the Raspberry pi 4. Open J1, J2 and J12 jumpers. No voltage should be observed respectively on pins A1-PAD10, A1-Pad11 and A1-Pad12. | -0.001V observed for each A1-Pad pins. => Validated.
Close J1, J2 and J12 jumpers with 3.3V. 3.3V should be observed respectively on pins A1-PAD10, A1-Pad11 and A1-Pad12. | 3.297V observed for each A1-Pad pins. => Validated.
Close J1, J2 and J12 jumpers with GND. continuity should be ensured between pins A1-PAD10, A1-Pad11 and A1-Pad12 and GND. | Continuity ensured between each A1-Pad pins and GND pins. => Validated.


A1-Pad10, A1-Pad11, A1-Pad12, 3.3V and GND pins map

Procedure | Results | Comments
Connect the board with the Raspberry pi 4. Check continuity of GPIO24 pins. A sound response should be heard. | Sound response heard. Continuity ensured between GPIO24 pins. => Validated.
Check continuity of GPIO25 pins. A sound response should be heard. | Sound response heard. Continuity ensured between GPIO25 pins. => Validated.
Check continuity of GPIO27 pins. A sound response should be heard. | Sound response heard. Continuity ensured between GPIO27 pins. => Validated.


GPIO 24, GPIO 25 and GPIO 27 pins map

# 4 Error report

## 4.1 Functionality

- MOSFETs mode (n-canal MOSFETs, initially in blocking mode) could be corrupted when voltage is not apply. If any doubt with continuity tests, double check with voltage application on drain pins or source pins. No voltage should be observed on complementary pins (drain/source or source/drain).
- MOSFETs passing mode do not respect the specifications. The gate commander UCC27324D is supply with 3.3V but operate properly at minimum 4V considering its datasheet. However UCC27324D operate with 3.3V without impact. The error concerns the conception of MOSFET logic with “alim_hat” board. Here we cut off 12V when GND should have been cut off. A modification of “alim_hat” board should resolve this error.

## 4.2 CAO/Fabrication

- Diode labels are not corresponding to the associated MOSFET (corrected on PCB).
- Connector labels are not corresponding to the associated MOSFET.

Ionospheric and Gamma-ray Observations Satellite Ref. XXX-YY-NN Edition 1 Date xx-xx-xx Revision 0 Date xx-xx-xx

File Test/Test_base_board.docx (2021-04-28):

NAFAbox “Base_hat” board test procedure

Abstract :

This document summarizes the specifications of the “base_hat” board of NAFAbox, present the tests procedures of these specifications, and expose the results.

| Date | Signature
Prepared by : - Guitton Thomas | 09/04/2021
Approved by :

Modification History
Ed. | Rev. | Date | Modifications | Visa
1 | 0

# 1 Glossaries

CAO GND PCB PWM | | Conception Assisté par Ordinateur (computer assisted conception) Ground Printed Circuit Board Pulse Width Modulation

# 2 Document Presentation

This document is training for electronic board test of NAFAbox project. It is a summary of the specification of the board, with associated tests to verify these specifications, and expose the result of these tests and concluded that the card is functioning properly or not.

# 3 Tests

## 3.1 Test 1: Visual check

Procedure | Results | Comments
Check solder: any pin without solder? No solder bridge? | No solder issues. => Validated.
Check components’ polarity. | No polarity issues. => Validated.
Check holes: isolation, metallicity, Via. | MK1, MK2, MK3 and MK4 isolation not respected. No metallicity issues. No Via issues. => Validated. | No impact but corrected on PCB.

## 3.2 Test 2: 5V equipotential

Procedure | Results | Comments
Connect the board with the powered “alim_hat” board. Check all 5V pins. 5V should be observed. | 5V observed for 40 pins header. 4.99V observed for ventilator. => Validated.


5V pins map

## 3.3 Test 3: 3.3V equipotential

Procedure | Results | Comments
Connect the board with the Raspberry pi 4. Check all 3.3V pins. 3.3V should be observed. | 3.297V observed for each 3.3V pins. => Validated.


3.3V pins map

## 3.4 Test 4: GND equipotential

Procedure | Results | Comments
Connect the board with the Raspberry pi 4. Check all GND pins. | Continuity ensured between GND pins. => Validated.


GND pins map

## 3.5 Test 5: CR2032 cell

Procedure | Results | Comments
Check 3V pin of the battery. 3V should be observed. | 3.004V observed with a multi-meter. The cell is charged. => Validated.


3V pins map

## 3.6 Test 6: Permanent time base

Procedure | Results | Comments
Supply with 3.3V from Raspberry pi 4. Request for date and time. Wait 5 minutes. Request for date and time. Check date and time provided. | Proper date and time after 5 minutes. => Validated. | U1 address : 1101001
Disconnect the Raspberry pi 4 supply (cell supply takes over). Wait 5 minutes. Request for date and time. Check date and time provided. | Proper date and time after 5 minutes. => Validated.


SDA pins and SCL pins map

## 3.7 Test 7: Ventilator

Procedure | Results | Comments
Connect the board with the Raspberry pi 4. With a PWM ratio of 0. Check ventilator’s rotation. No movement should be observed. | No rotation observed. => Validated. | GPIO12 (PWM). Without command on GPIO12, the ventilator functioning at max speed. 0<PWM<1023 .
Increase the PWM until ventilator’s rotation start. | Rotation start at PWM = 60. Rotation stop under PWM = 40. => Validated. | PWM_(start) =60 PWM_(mini) =40
Increase the PWM. The rotor should accelerate. | Acceleration observed when PWM increase. => Validated.


PWM pins map

# 4 Error report

## 4.1 Functionality

- No functionality error.

## 4.2 CAO/Fabrication

- Ventilator’s 3D model is mounted upside down on PCB.
- Missing isolation on MK1, MK2, MK3 and MK4 mounting holes (corrected on PCB).

Ionospheric and Gamma-ray Observations Satellite Ref. XXX-YY-NN Edition 1 Date xx-xx-xx Revision 0 Date xx-xx-xx

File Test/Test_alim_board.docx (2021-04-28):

NAFAbox “Alim_hat” board test procedure

Abstract :

This document summarizes the specifications of the “Alim_hat” board of NAFAbox, present the tests procedures of these specifications, and expose the results.

| Date | Signature
Prepared by : - Guitton Thomas | 07/04/2021
Approved by :

Modification History
Ed. | Rev. | Date | Modifications | Visa
1 | 0

# 1 Glossaries

PCB CAO MOSFET DC GND | | Printed Circuit Board Conception Assisté par Ordinateur (computer assisted conception) Metal Oxide Semiconductor Field Effect Transistor Direct Current Ground

# 2 Document Presentation

This document is training for electronic board test of NAFAbox project. It is a summary of the specification of the board, with associated tests to verify these specifications, and expose the result of these tests and concluded that the card is functioning properly or not.

# 3 Tests

## 3.1 Test 1: Visual check

Procedure | Results | Comments
Check solder: any pin without solder? No solder bridge? | No solder issues. => Validated.
Check components’ polarity. | No polarity issues. => Validated.
Check holes: isolation, metallicity, Via. | MK1 and MK4 isolation not respected. No metallicity issues. No Via issues. => Validated. | No impact but corrected on PCB.

## 3.2 Test 2: 12V equipotential

Procedure | Results | Comments
Supply the board with 12V on J1 or J2 connectors. Check all 12V pins. 12V should be observed. | 12.04V observed for each 12V pins. => Validated.
For each jack DC connector (J4, J5, J6 and J7): Open “ON/OFF” jumper. Check the output voltage of Jack DC connectors. No voltage should be observed. | 0.002V observed for Jack DC V+ pins. => Validated.
Close “ON/OFF” jumper. Check the output voltage of Jack DC connectors. 12V should be observed. | 12.04V observed for Jack DC V+ pins. => Validated.


12V and Jack DC V+ pins map

## 3.3 Test 3: VCC equipotential

Procedure | Results | Comments
Supply the board with VCC on J1 connector. Check all VCC pins. VCC voltage should be observed. | VCC was chosen to be 5V. 5.01V observed for each VCC pins. => Validated.


VCC pins map

## 3.4 Test 4: 5V equipotential

Procedure | Results | Comments
Supply the board with 12V on J1 or J2 connectors. Open “ON/OFF 5V” jumper and check all 5V pins. No voltage should be observed. | 0.001V observed for each 5V pins. => Validated.
Close “ON/OFF 5V” jumper and check all 5V pins. 5V should be observed. | 5.01V observed for each 5V pins. => Validated.
With a heating resistor consuming 1A at 5V, check the behavior of the converter. 5V should be observed. | 4.98V observed for 5V pins of the 40 pins header with 0.853A. => Validated. | Power losses due to the wiring of the instruments.
With a heating resistor consuming 2A at 5V, check the behavior of the converter. 5V should be observed. | 4.95V observed for 5V pins of the 40 pins header with 2.05A. => Validated. | Power losses due to the wiring of the instruments. (Uses of 3 heat resistor consuming 1A at 5V).
With a heating resistor consuming 3A at 5V, check the behavior of the converter. 5V should be observed. | Not tested. | No device consuming 3A at 5V at disposal.


5V pins map

## 3.5 Test 5: 3.3V equipotential

Procedure | Results | Comments
Connect the board with the Raspberry pi 4. Check all 3.3V pins. 3.3V should be observed. | 3.295V observed for each 3.3V pins. => Validated.


3.3V pins map

## 3.6 Test 6: GND equipotential

Procedure | Results | Comments
Connect the board with the Raspberry pi 4. Check all GND pins. | Continuity ensured between GND pins. => Validated.


GND pins map

## 3.7 Test 7: reverse current protection

Procedure | Results | Comments
Check continuity between MOSFET drain and gnd_no with a multi-meter in test mode. A sound response should be heard. | Sound response heard. Continuity is ensured between MOSFET drain and gnd_no. => Validated.
Supply 12V on J1 connector. A voltage should be observed on Jack DC output. | 12V observed on oscilloscope. Closed circuit. => Validated.
Invert 12V and GND wires for J1 connector. No voltage should be observed on Jack DC output. | 0V observed on oscilloscope. Open circuit. => Validated.
Repeat for J2 connector for 12V supply. | Same observation as for J1 connector. => Validated.


MOSFET drain

gnd_no pins map

## 3.8 Test 8: 5A auto-resettable fuses

Procedure | Results | Comments
For each fuse (F2, F3, F4 and F5): Check continuity between fuse terminals with a multi-meter in test mode. A sound response should be heard. | Sound response heard. Continuity is ensured between fuse terminals. => Validated.
Close associated “ON/OFF” jumper and provides 12V/5A to the fuse. Check with the ohmmeter. “0.L” should be observed. | Current drop observed on the supply. Fuse disarmed. => Validated. | Because of the speed of rearmament, check current drop on the supply.
Wait for fuse to rearm. Assert continuity between fuse terminals. | Sound response heard. Continuity is ensured between fuse terminals. => Validated. | The rearmament is quasi instantaneous.


Fuse pins map

## 3.9 Test 9: INA219 communication

Procedure | Results | Comments
Connect the board with the Raspberry pi 4. For each INA219 (U1, U2, U3 and U4): With a heating resistor consuming 2.5A at 12V connected to the corresponding Jack DC connector, request for current and voltage in I2C. 12V and 2.5A should be returned. | U1: Test without current: return 11.86V and 0.001A Test with current: return 11.69V and 2.31A => Validated. U2: Test without current: return 12.04V and 0.001A Test with current: return 11.69V and 2.18A => Validated. U3: Test without current: return 12.01V and 0.001A Test with current: return 11.68V and 2.22A => Validated. U4: Test without current: return 12.01V and 0.001A Test with current: return 11.68V and 2.19A => Validated. | U1 address : 1000001 U2 address : 1001001 U3 address : 1000011 U4 address : 1000100 slight tension drop.


SDA pins and SCL pins map

## 3.10 Test 10: Full board supply compliance

Procedure | Results | Comments
Test multiple Jack DC outputs simultaneously. 12V should be observed for each output. | For two Jack DC outputs connected with a heating resistor 12V/2.5A and with a heating resistor 12V/0.6A. Respectively 11.62V/2A and 11.02V/0.6A observed. => Validated.
With all jumper closed, use a voltage supply able to deliver 180W, regulate the voltage to 12V and limit the current to 10A and increase the limit until 15A. No voltage drop should be observed. | Not tested. | No device consuming 10A/15A at 12V at disposal.

# 4 Error report

## 4.1 Functionality

- No certitude of proper functioning of the DC to DC converter with 3A (test until ~2A).
- No certitude of proper functioning of the full board supplied with 12V/15A.

## 4.2 CAO/Fabrication

- Isolation of mounting-hole MK1 must be 1.5 instead of 0. The 5V track preventing the isolation (corrected on PCB).
- Isolation of mounting-hole MK4 must be 1.5 instead of 1.2 (corrected on PCB).
- Inversion of J2 pins (corrected on PCB).

Ionospheric and Gamma-ray Observations Satellite Ref. XXX-YY-NN Edition 1 Date xx-xx-xx Revision 0 Date xx-xx-xx

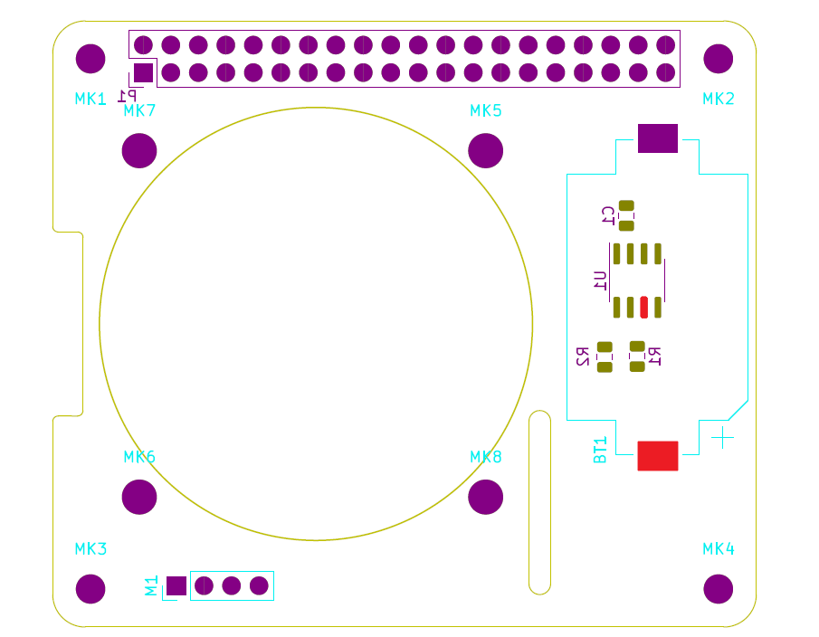
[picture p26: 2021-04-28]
Test/base images/pins_base_3V.png

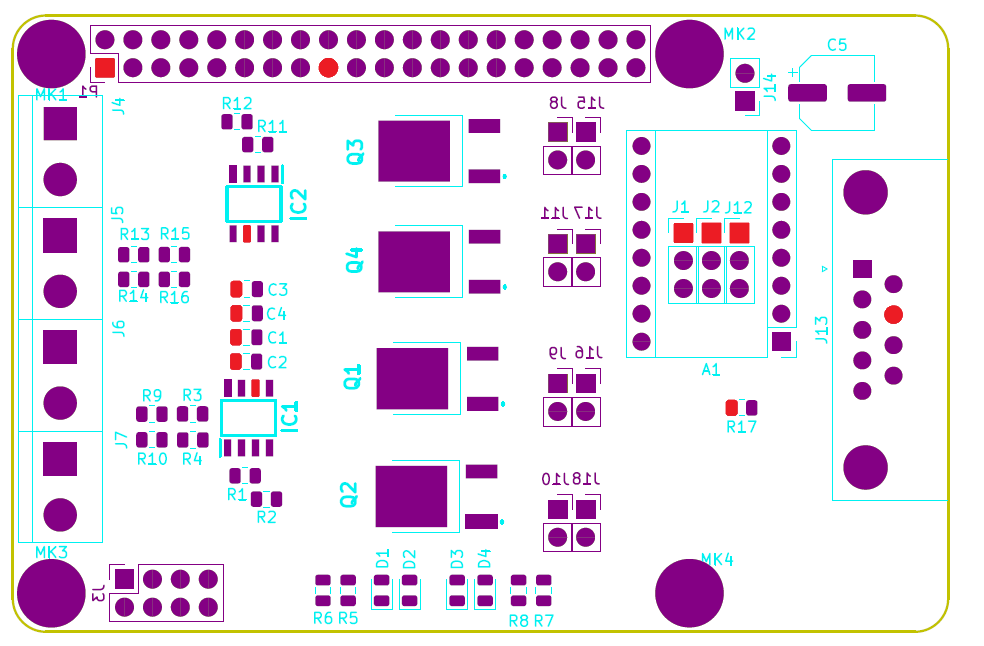
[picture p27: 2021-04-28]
Test/relais images/pins_relais_3.3V.png

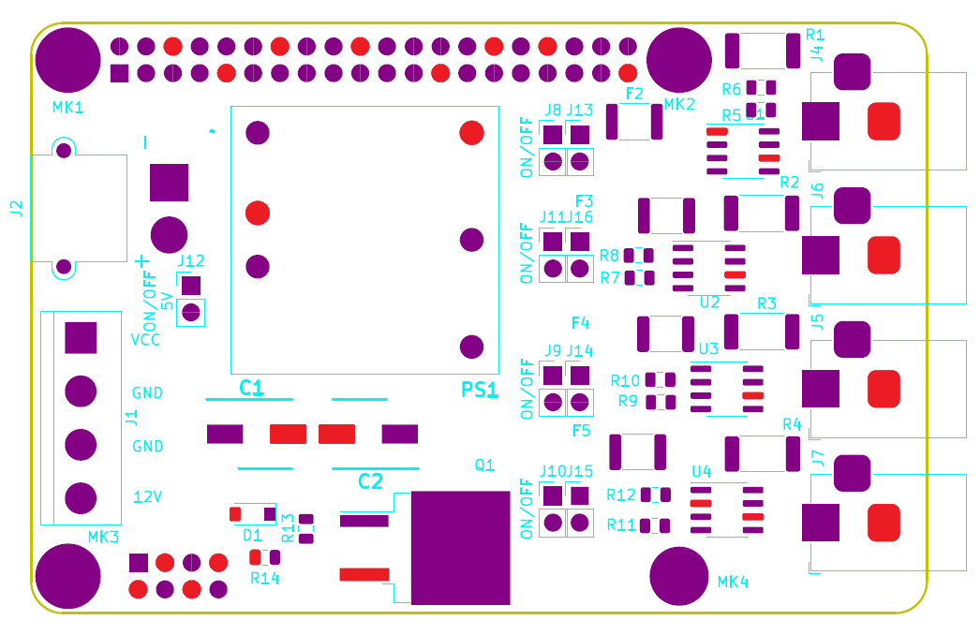
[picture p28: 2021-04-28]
Test/alim images/pins_alim_gnd.png

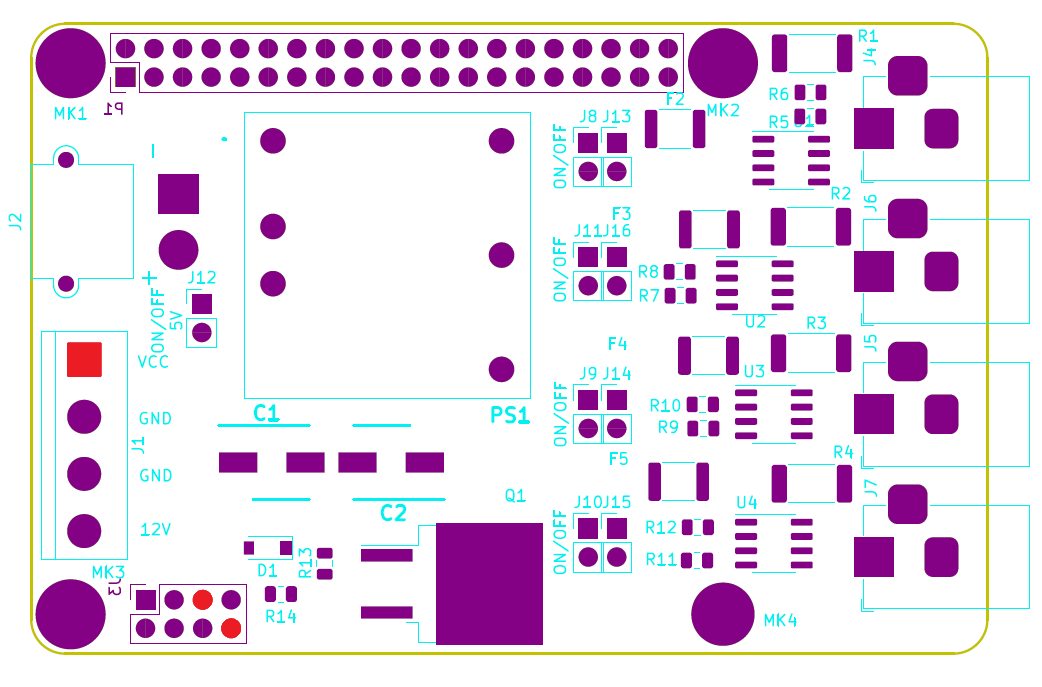
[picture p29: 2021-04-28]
Test/alim images/pins_alim_VCC.png

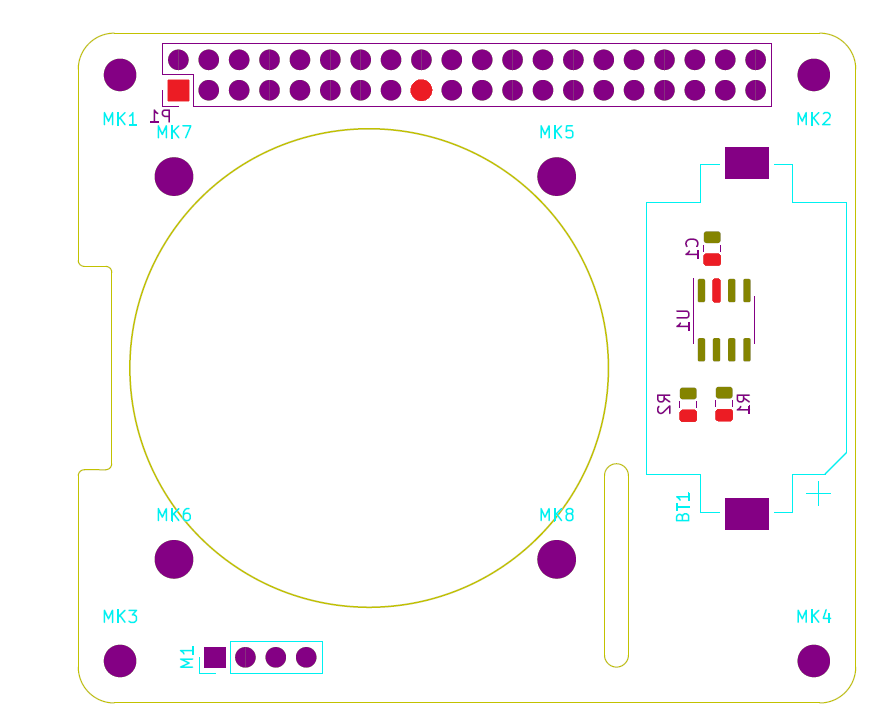
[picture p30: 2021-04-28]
Test/base images/pins_base_3.3V.png

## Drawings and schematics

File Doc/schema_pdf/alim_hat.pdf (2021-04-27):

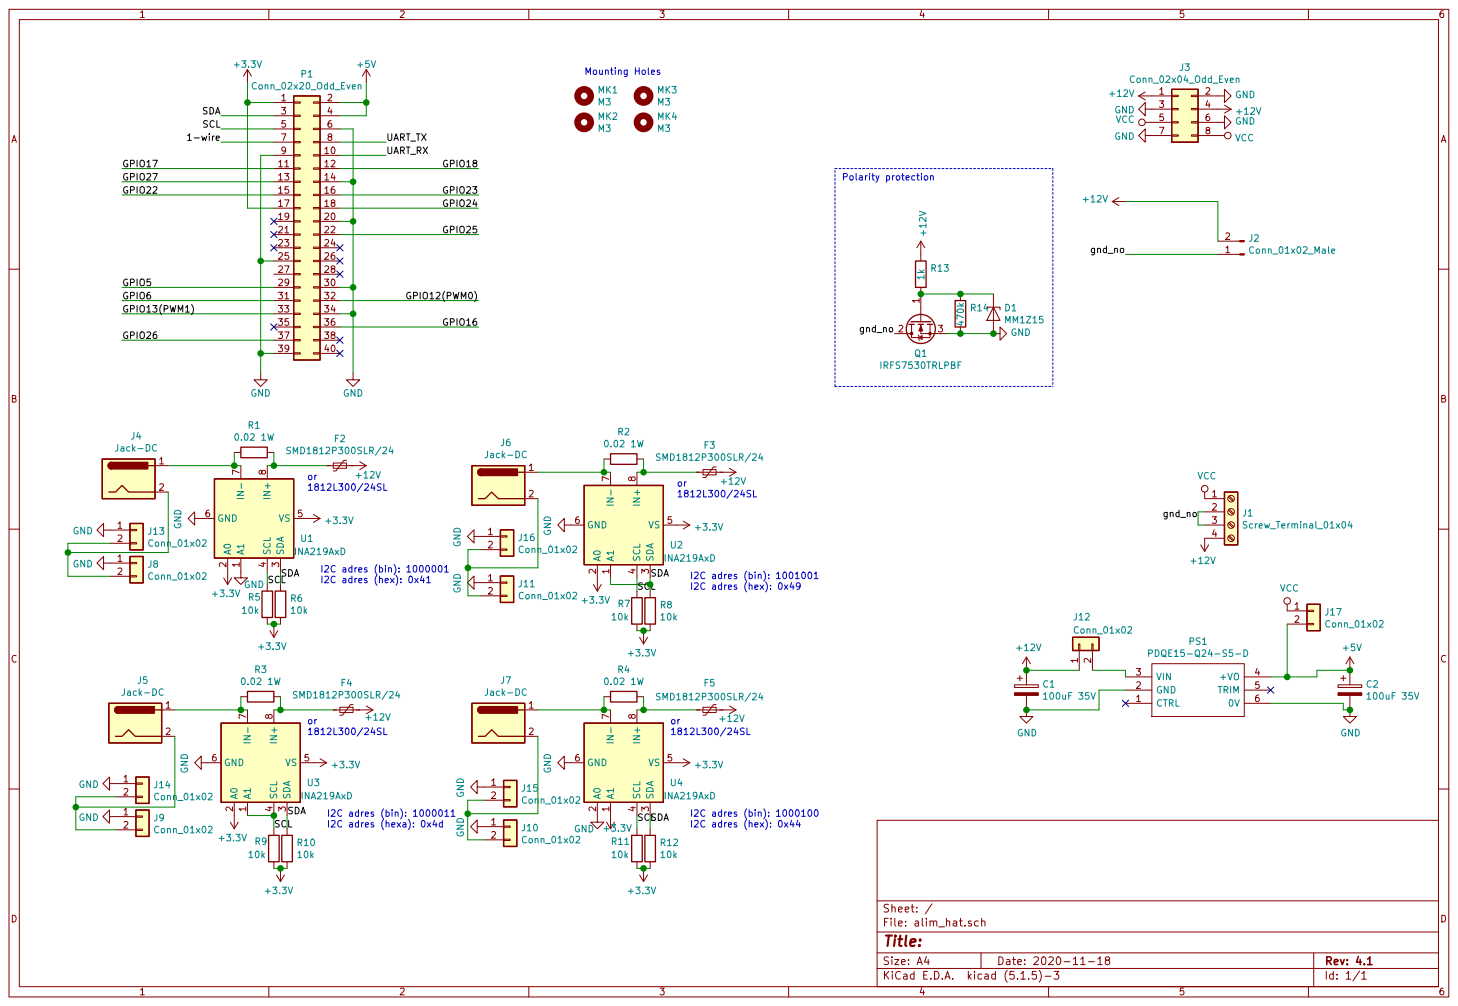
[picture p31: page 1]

4 VS 5 GND 6 IN- 7 IN+

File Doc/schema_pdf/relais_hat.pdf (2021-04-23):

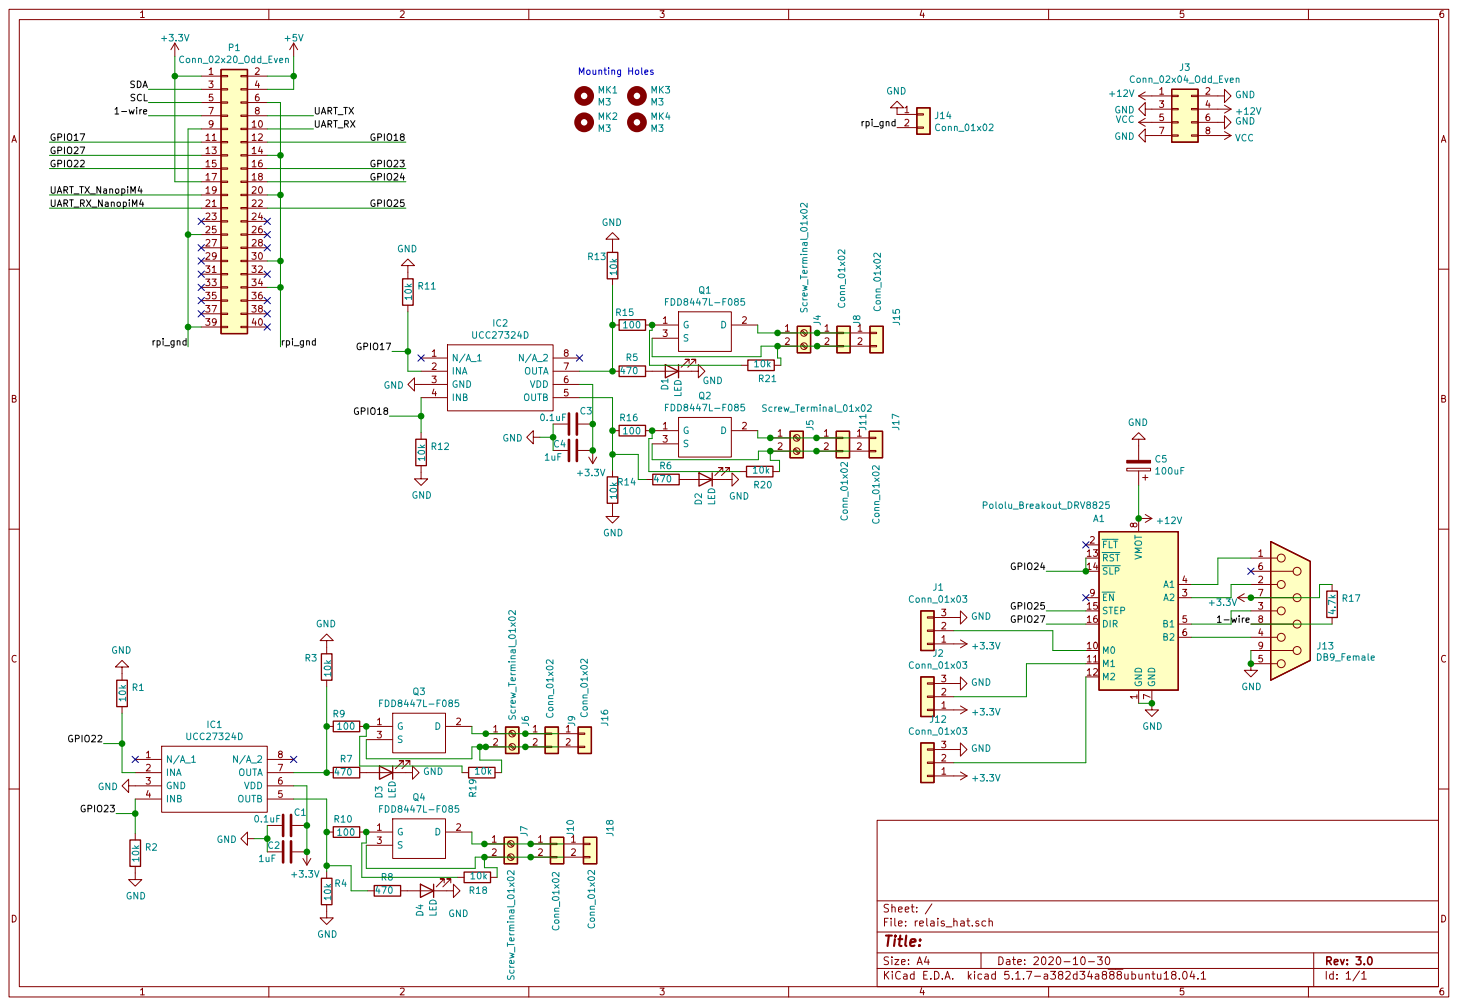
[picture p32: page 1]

INA 2 GND 3 | 470

1 M0 10 M1 11 M2 12 RST 13 SLP 14 STEP 15 DIR 16 FLT 2 A2 3 A1 4 B1 5 B2 6 GND

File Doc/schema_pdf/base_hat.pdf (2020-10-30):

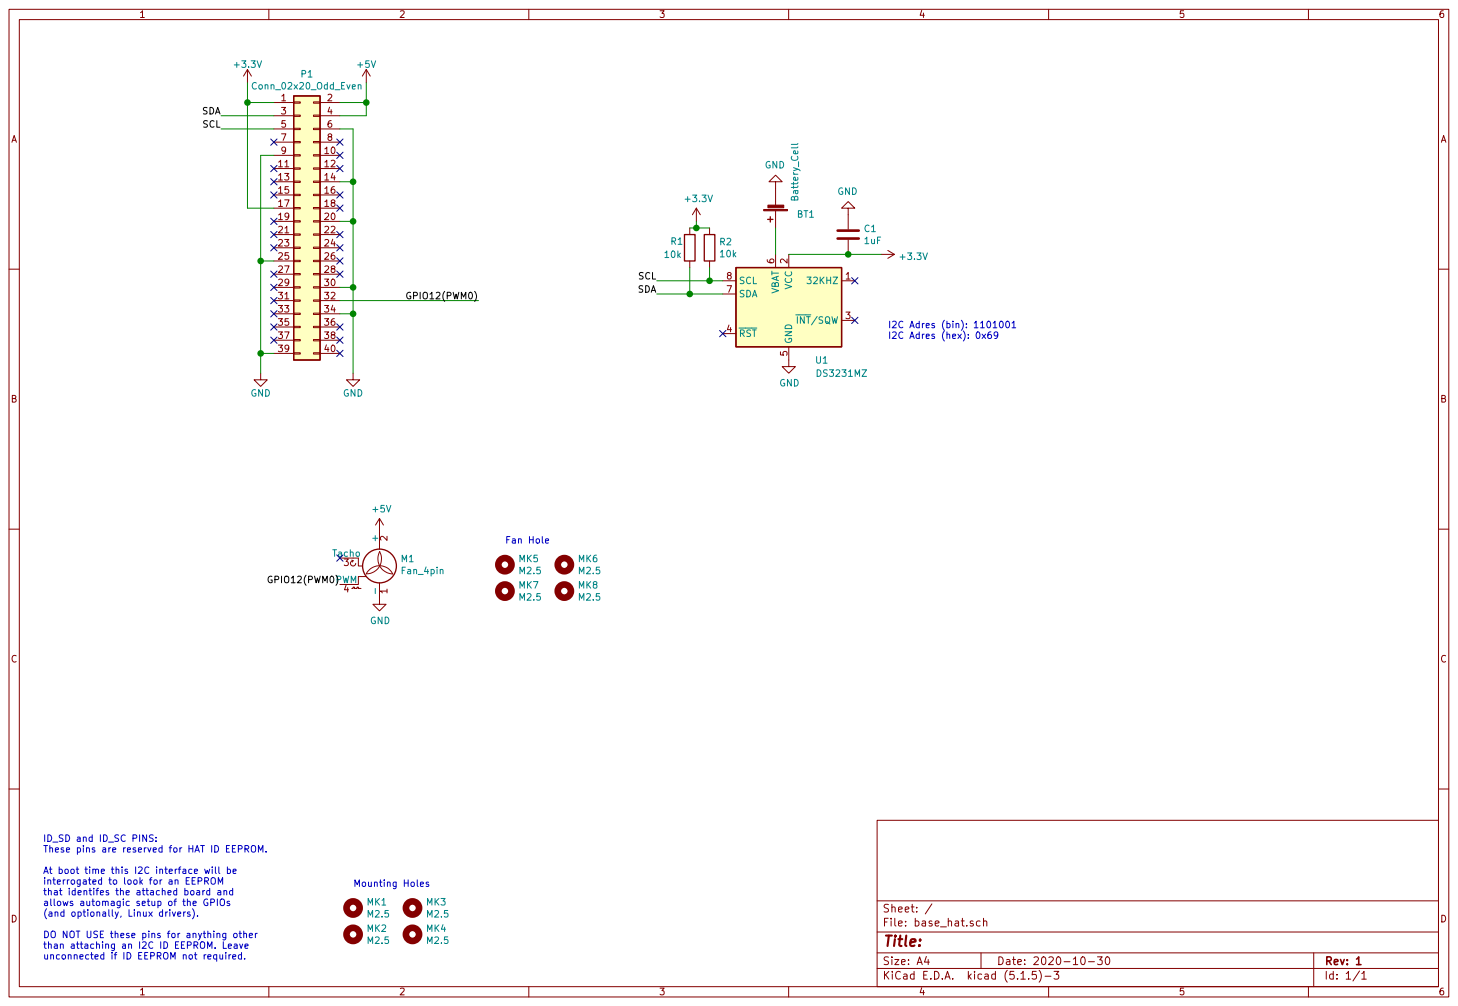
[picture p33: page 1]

Fan Hole Mounting Holes

ID_SD and ID_SC PINS: These pins are reserved for HAT ID EEPROM. At boot time this I2C interface will be

interrogated to look for an EEPROM
that identifes the attached board and
allows automagic setup of the GPIOs
(and optionally, Linux drivers).
DO NOT USE these pins for anything other
than attaching an I2C ID EEPROM. Leave
unconnected if ID EEPROM not required.

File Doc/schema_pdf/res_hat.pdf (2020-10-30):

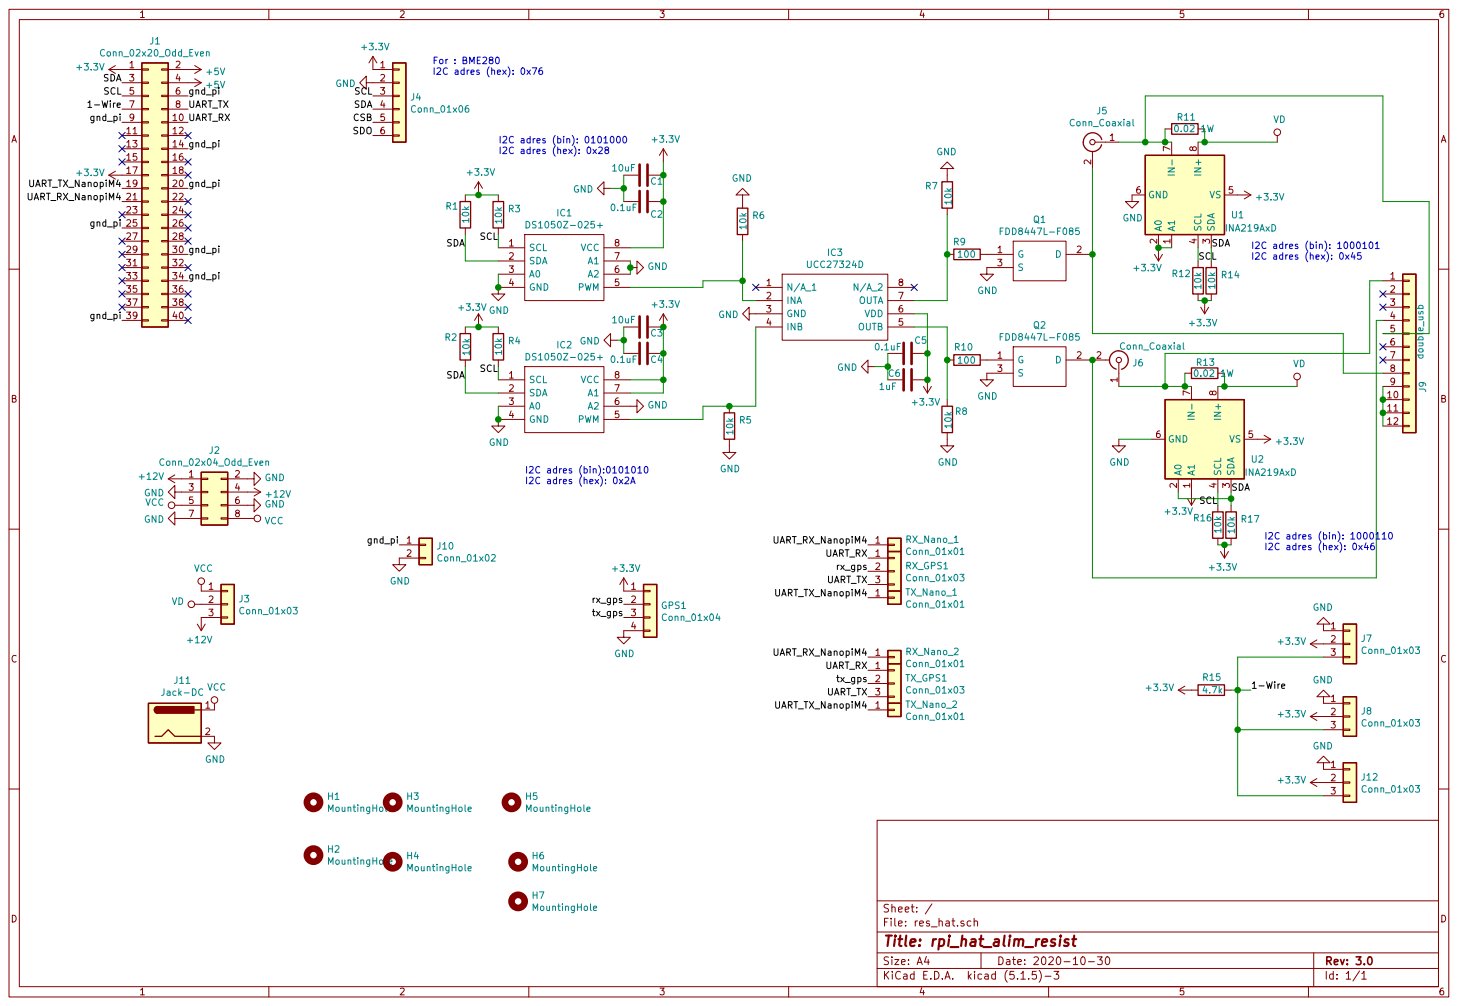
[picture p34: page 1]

4 VS 5 GND 6 IN- 7 IN+

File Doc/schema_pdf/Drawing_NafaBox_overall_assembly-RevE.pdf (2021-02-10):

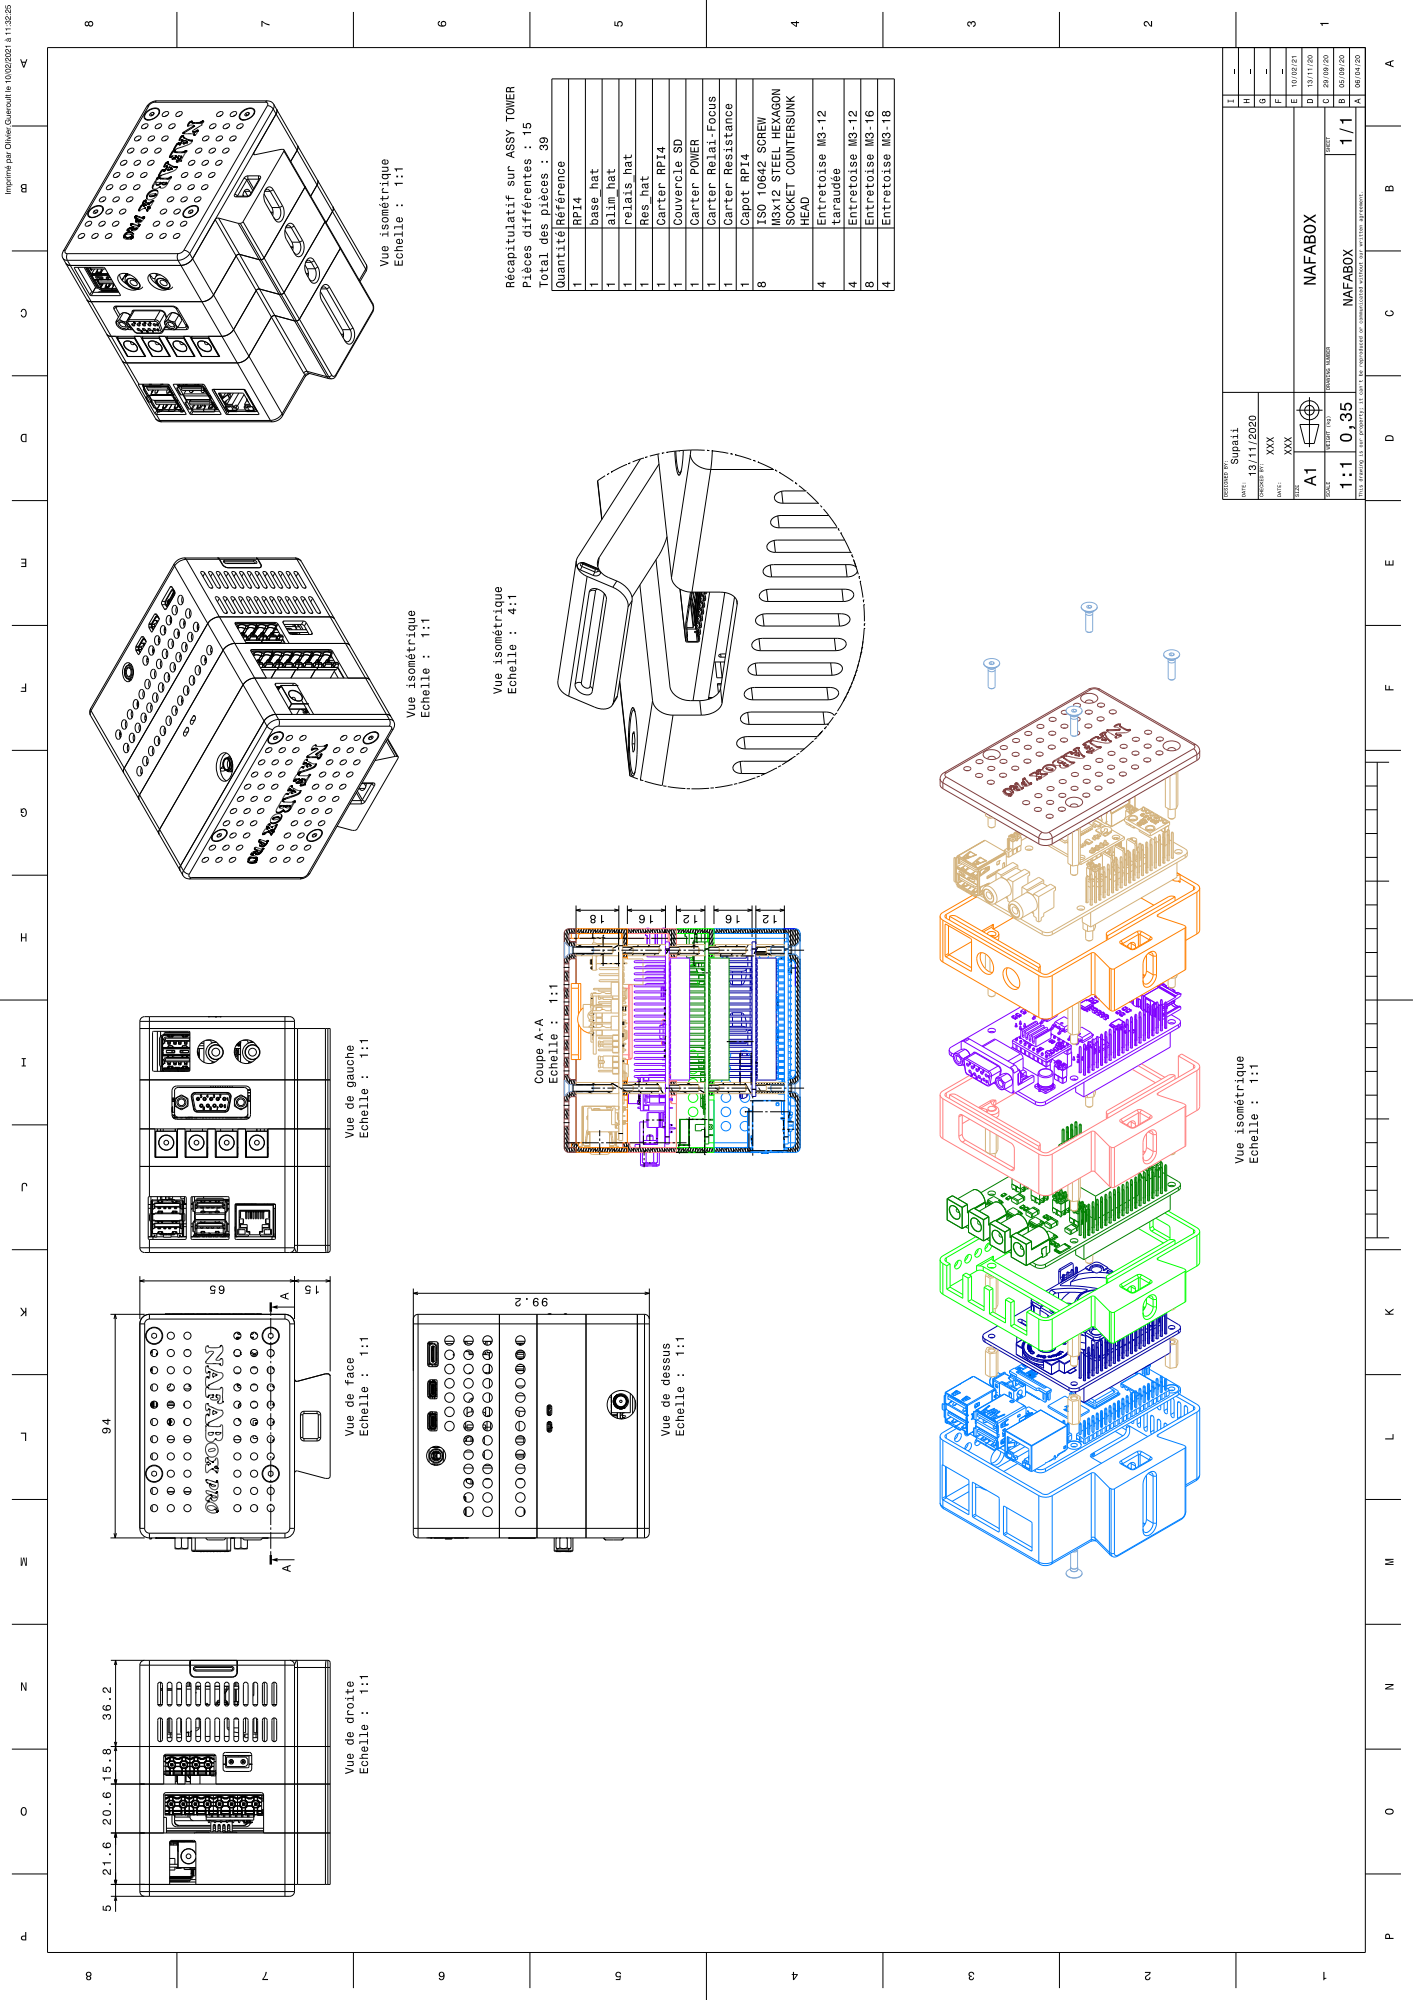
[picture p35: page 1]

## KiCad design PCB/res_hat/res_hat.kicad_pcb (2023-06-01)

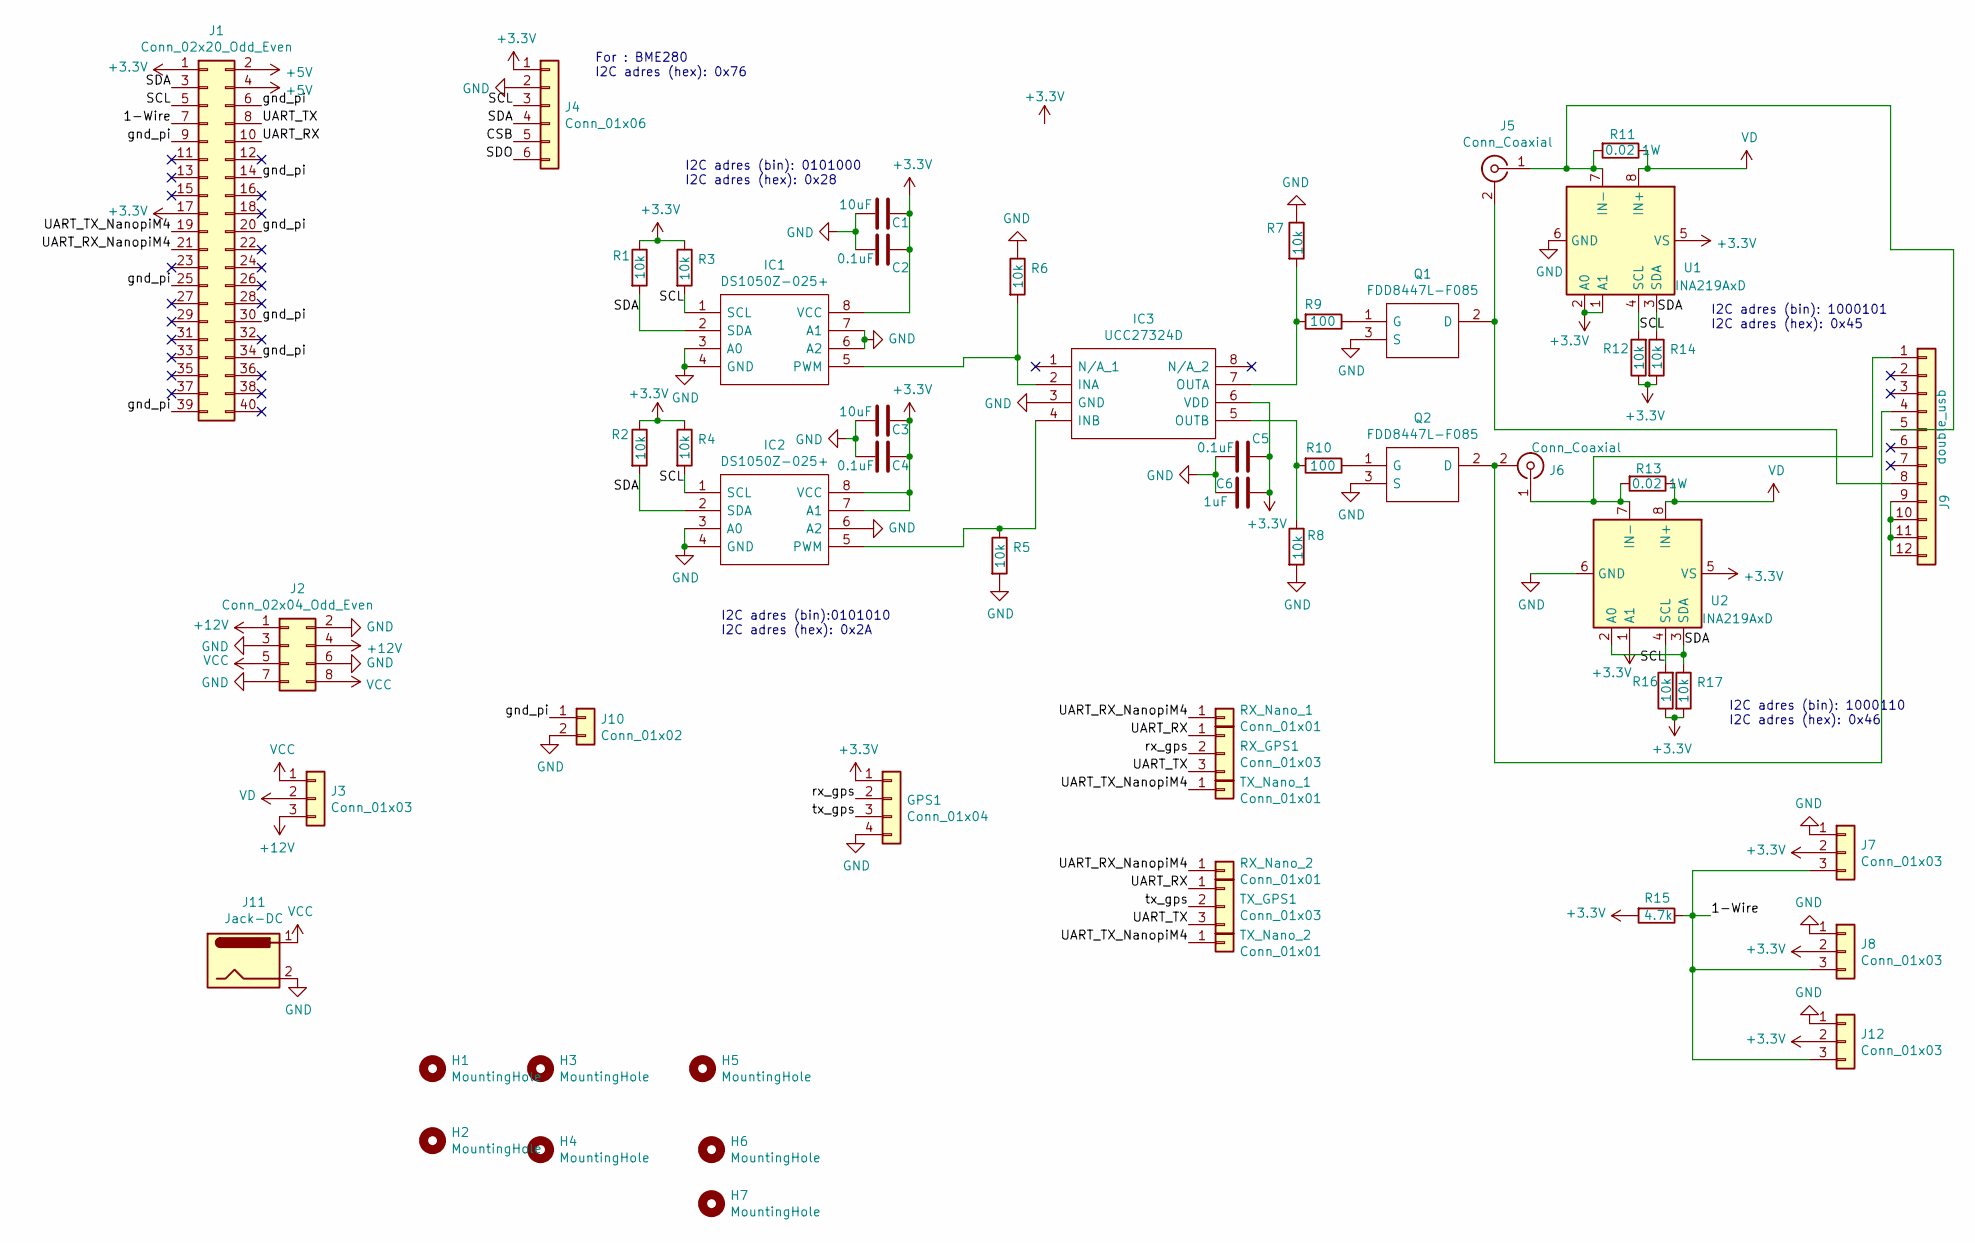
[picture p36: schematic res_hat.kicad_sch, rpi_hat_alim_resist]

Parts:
C1, C3: 10uF; C_0805_2012Metric; LCSC C15850
C2, C4, C5: 0.1uF; C_0805_2012Metric; LCSC C49678
C6: 1uF; C_0805_2012Metric; LCSC C28323
GPS1: Conn_01x04; PinSocket_1x04_P2.54mm_Vertical
H1, H2, H3, H4, H5, H6, H7: MountingHole; MountingHole_3.2mm_M3
IC1, IC2: DS1050Z-025+; SOIC127P600X175-8N; Mouser Part Number 700-DS1050Z-025
IC3: UCC27324D; SOIC127P600X175-8N; Mouser Part Number 595-UCC27324D
J1: Conn_02x20_Odd_Even; PinHeader_2x20_P2.54mm_Vertical
J2: Conn_02x04_Odd_Even; PinHeader_2x04_P2.54mm_Vertical
J3: Conn_01x03; PinHeader_1x03_P2.54mm_Vertical
J4: Conn_01x06; PinHeader_1x06_P2.54mm_Vertical
J5, J6: Conn_Coaxial; KLPX0848A2O
J7, J8, J12: Conn_01x03; Molex_KK-254_AE-6410-03A_1x03_P2.54mm_Vertical
J9: double_usb; DUAL_USB_2.0_TYPE-A
J10: Conn_01x02; PinHeader_1x02_P2.54mm_Vertical
J11: Jack-DC; BarrelJack_Horizontal
Q1, Q2: FDD8447L-F085; FDD8447LF085; Mouser Part Number 512-FDD8447L_F085
R1, R2, R3, R4, R5, R6, R7, R8, R12, R14, R16, R17: 10k; R_0805_2012Metric; LCSC C17414
R9: 100; R_0805_2012Metric; LCSC C17414
R10: 100; R_0805_2012Metric; LCSC C17408
R11, R13: 0.02 1W; R_2512_6332Metric; LCSC C127705
R15: 4.7k; R_0805_2012Metric; LCSC C17673
RX_GPS1: Conn_01x03; PinHeader_1x03_P2.54mm_Vertical
RX_Nano_1, RX_Nano_2: Conn_01x01; PinHeader_1x01_P2.54mm_Vertical
TX_GPS1: Conn_01x03; PinHeader_1x03_P2.54mm_Vertical
TX_Nano_1, TX_Nano_2: Conn_01x01; PinHeader_1x01_P2.54mm_Vertical
U1, U2: INA219AxD; SOIC-8_3.9x4.9mm_P1.27mm; LCSC C138706

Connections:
+5V: J1.2, J1.4
+12V: J2.1, J2.4, J3.3
/1-Wire: J1.7, J7.3, J8.3, J12.3, R15.1
/CSB: J4.5
/SCL: IC1.1 (SCL), IC2.1 (SCL), J1.5, J4.3, R3.2, R4.2, R12.2, R16.2, U1.4 (SCL), U2.4 (SCL)
/SDA: IC1.2 (SDA), IC2.2 (SDA), J1.3, J4.4, R1.2, R2.2, R14.1, R17.1, U1.3 (SDA), U2.2 (A0), U2.3 (SDA)
/SDO: J4.6
/UART_RX: J1.10, RX_GPS1.1, TX_GPS1.1
/UART_RX_NanopiM4: J1.21, RX_Nano_1.1, RX_Nano_2.1
/UART_TX: J1.8, RX_GPS1.3, TX_GPS1.3
/UART_TX_NanopiM4: J1.19, TX_Nano_1.1, TX_Nano_2.1
/gnd_pi: J1.6, J1.9, J1.14, J1.20, J1.25, J1.30, J1.34, J1.39, J10.1
/rx_gps: GPS1.2, RX_GPS1.2
/tx_gps: GPS1.3, TX_GPS1.2
GND: C1.1, C2.1, C3.1, C4.1, C5.2, C6.2, GPS1.4, IC1.3 (A0), IC1.4 (GND), IC1.6 (A2), IC1.7 (A1), IC2.3 (A0), IC2.4 (GND), IC2.6 (A2), IC3.3 (GND), J2.2, J2.3, J2.6, J2.7, J4.2, J7.1, J8.1, J10.2, J11.2, J12.1, Q1.3 (S), Q2.3 (S), R5.2, R6.1, R7.1, R8.2, U1.6 (GND), U2.6 (GND)
unnamed: IC1.5 (PWM), IC3.2 (INA), R6.2
unnamed: IC2.5 (PWM), IC3.4 (INB), R5.1
unnamed: IC3.7 (OUTA), R7.2, R9.2
unnamed: IC3.5 (OUTB), R8.1, R10.2
unnamed: J5.2 (Ext), J9.8, Q1.2 (D)
unnamed: J5.1 (In), J9.5, R11.2, U1.7 (IN-)
unnamed: J6.2 (Ext), J9.4, Q2.2 (D)
unnamed: J6.1 (In), J9.1, R13.2, U2.7 (IN-)
unnamed: J9.9, J9.10, J9.11, J9.12
unnamed: Q1.1 (G), R9.1
unnamed: Q2.1 (G), R10.1
VCC: J2.5, J2.8, J3.1, J11.1
VD: J3.2, R11.1, R13.1, U1.8 (IN+), U2.8 (IN+)

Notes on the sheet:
I2C adres (bin): 1000110 I2C adres (hex): 0x46
For : BME280 I2C adres (hex): 0x76
I2C adres (bin):0101010 I2C adres (hex): 0x2A
I2C adres (bin): 0101000 I2C adres (hex): 0x28
I2C adres (bin): 1000101 I2C adres (hex): 0x45

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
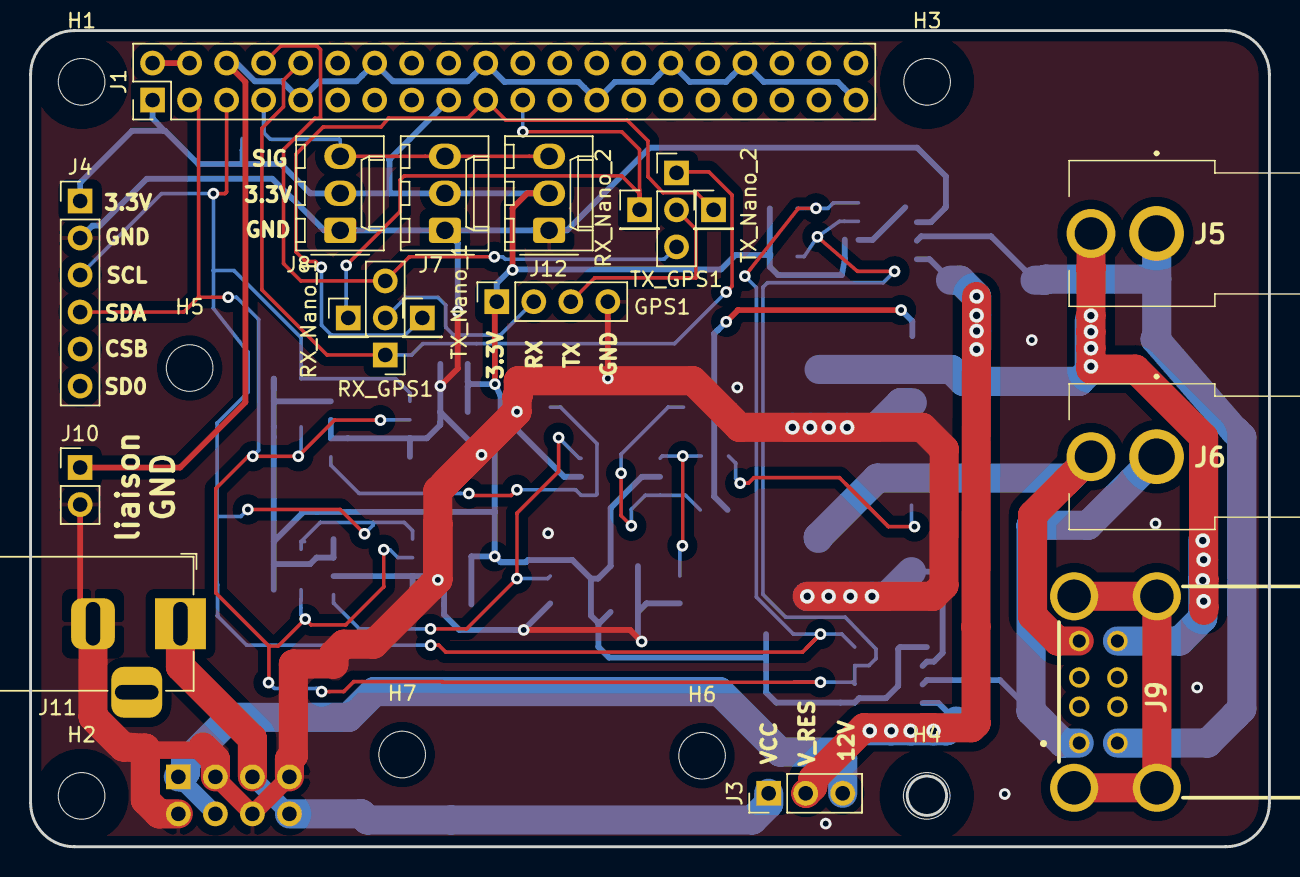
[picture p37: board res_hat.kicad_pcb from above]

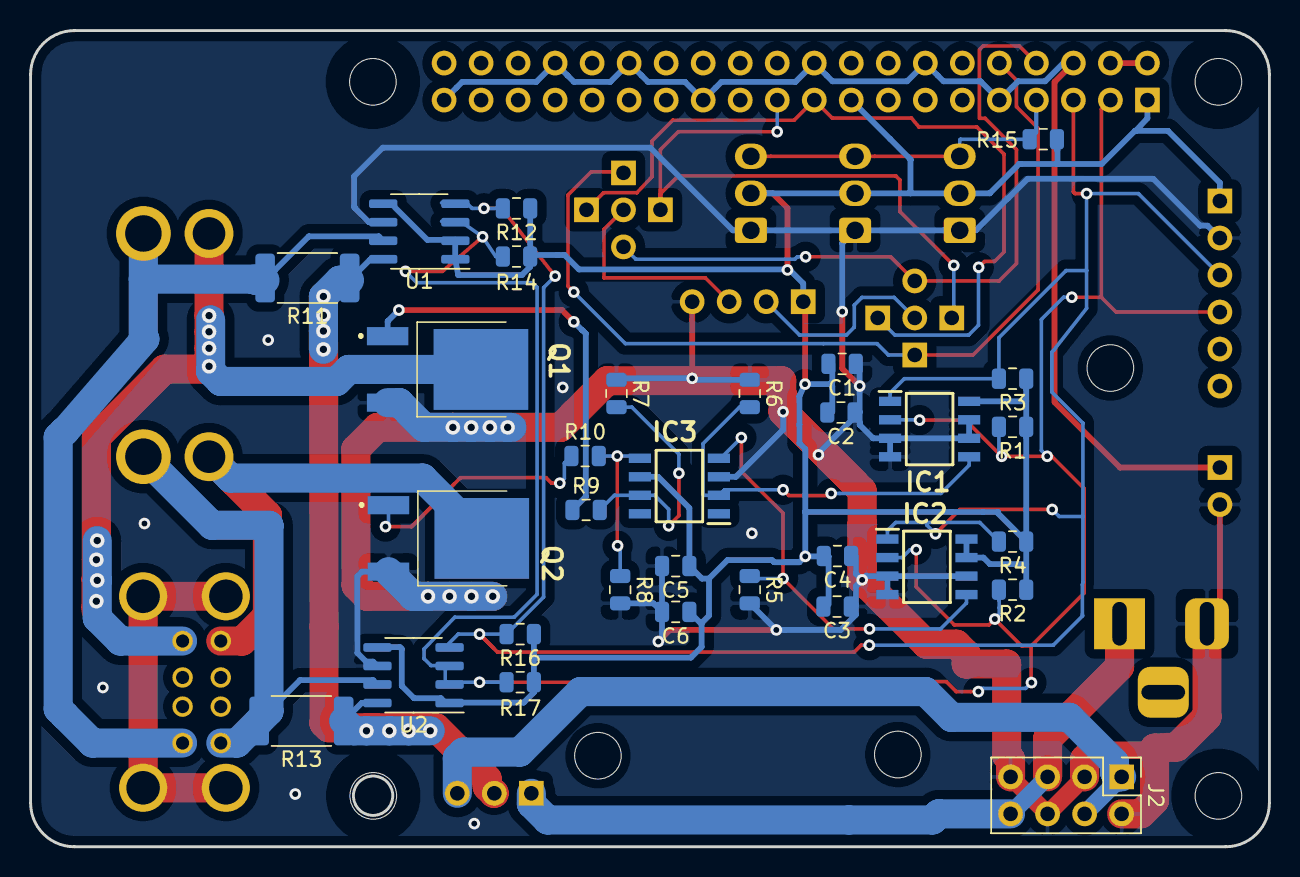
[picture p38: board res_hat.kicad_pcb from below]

Board: 2 copper layers, 85.0 x 56.0 mm, 56 parts (31 on the bottom side), 28 nets.

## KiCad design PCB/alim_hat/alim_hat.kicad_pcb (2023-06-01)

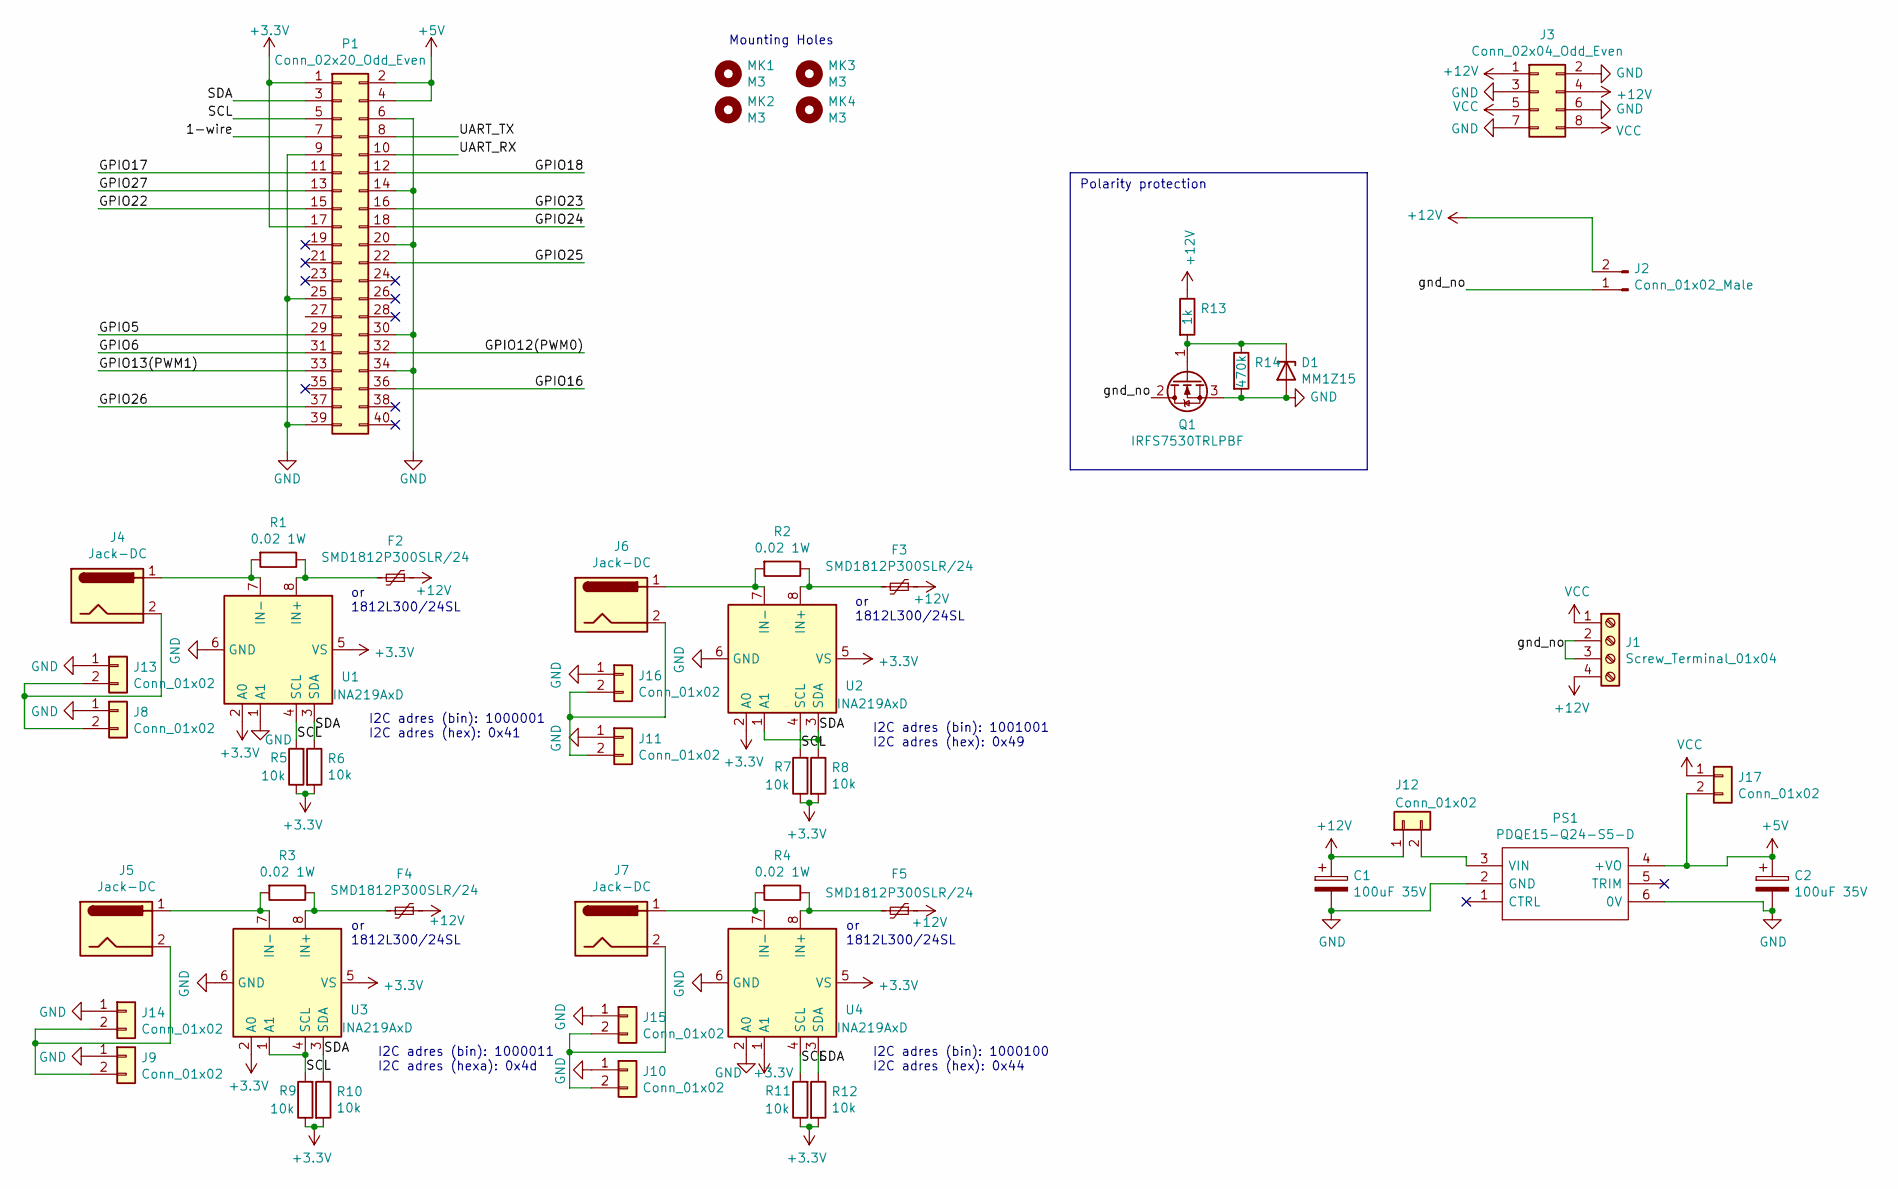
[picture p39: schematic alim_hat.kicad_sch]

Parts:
C1, C2: 100uF 35V; CP_Elec_6.3x7.7; LCSC C134792
D1: MM1Z15; D_SOD-123; LCSC C86235
F2, F3, F4: SMD1812P300SLR/24; Fuse_1812_4532Metric; LCSC C495359
F5: SMD1812P300SLR/24; Fuse_1812_4532Metric; LCSC SMD1812P300SLR/24
J1: Screw_Terminal_01x04; TerminalBlock_bornier-4_P5.08mm
J2: Conn_01x02_Male; AMASS_XT30PW-M_1x02_P2.50mm_Horizontal
J3: Conn_02x04_Odd_Even; PinHeader_2x04_P2.54mm_Vertical
J4, J5, J6, J7: Jack-DC; BarrelJack_Horizontal
J8, J9, J10, J11, J12, J13, J14, J15, J16, J17: Conn_01x02; PinHeader_1x02_P2.54mm_Vertical
MK1, MK2, MK3, MK4: M3; MountingHole_3.2mm_M3
P1: Conn_02x20_Odd_Even; PinSocket_2x20_P2.54mm_Vertical
PS1: PDQE15-Q24-S5-D; PDQE15Q24S5D; Manufacturer_Part_Number PDQE15-Q24-S5-D
Q1: IRFS7530TRLPBF; TO-263-2; LCSC C500544
R1, R2, R3, R4: 0.02 1W; R_2512_6332Metric; LCSC C127705
R5, R6, R7, R8, R9, R10, R11, R12: 10k; R_0805_2012Metric; LCSC C17414
R13: 1k; R_0805_2012Metric; LCSC C17513
R14: 470k; R_0805_2012Metric; LCSC C17709
U1, U2, U3, U4: INA219AxD; SOIC-8_3.9x4.9mm_P1.27mm; LCSC C138706

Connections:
+3.3V: P1.1, P1.17, R5.1, R6.2, R7.1, R8.2, R9.1, R10.2, R11.1, R12.2, U1.2 (A0), U1.5 (VS), U2.2 (A0), U2.5 (VS), U3.2 (A0), U3.5 (VS), U4.1 (A1), U4.5 (VS)
+5V: C2.1, J17.2, P1.2, P1.4, PS1.4 (+VO)
+12V: C1.1, F2.1, F3.1, F4.1, F5.1, J1.4, J2.2, J3.1, J3.4, J12.1, R13.1
/1-wire: P1.7
/GPIO5: P1.29
/GPIO6: P1.31
/GPIO12(PWM0): P1.32
/GPIO13(PWM1): P1.33
/GPIO16: P1.36
/GPIO17: P1.11
/GPIO18: P1.12
/GPIO22: P1.15
/GPIO23: P1.16
/GPIO24: P1.18
/GPIO25: P1.22
/GPIO26: P1.37
/GPIO27: P1.13
/SCL: P1.5, R5.2, R7.2, R9.2, R11.2, U1.4 (SCL), U2.4 (SCL), U3.1 (A1), U3.4 (SCL), U4.4 (SCL)
/SDA: P1.3, R6.1, R8.1, R10.1, R12.1, U1.3 (SDA), U2.1 (A1), U2.3 (SDA), U3.3 (SDA), U4.3 (SDA)
/UART_RX: P1.10
/UART_TX: P1.8
/gnd_no: J1.2, J1.3, J2.1, Q1.2 (D)
GND: C1.2, C2.2, D1.2 (A), J3.2, J3.3, J3.6, J3.7, J8.1, J9.1, J10.1, J11.1, J13.1, J14.1, J15.1, J16.1, P1.6, P1.9, P1.14, P1.20, P1.25, P1.30, P1.34, P1.39, PS1.2 (GND), PS1.6 (0V), Q1.3 (S), R14.2, U1.1 (A1), U1.6 (GND), U2.6 (GND), U3.6 (GND), U4.2 (A0), U4.6 (GND)
unnamed: D1.1 (K), Q1.1 (G), R13.2, R14.1
unnamed: J7.2, J10.2, J15.2
unnamed: J6.2, J11.2, J16.2
unnamed: J12.2, PS1.3 (VIN)
unnamed: J4.2, J8.2, J13.2
unnamed: J5.2, J9.2, J14.2
unnamed: F2.2, R1.1, U1.8 (IN+)
unnamed: J4.1, R1.2, U1.7 (IN-)
unnamed: F3.2, R2.1, U2.8 (IN+)
unnamed: J6.1, R2.2, U2.7 (IN-)
unnamed: F4.2, R3.1, U3.8 (IN+)
unnamed: J5.1, R3.2, U3.7 (IN-)
unnamed: F5.2, R4.1, U4.8 (IN+)
unnamed: J7.1, R4.2, U4.7 (IN-)
VCC: J1.1, J3.5, J3.8, J17.1

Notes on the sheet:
or 1812L300/24SL
I2C adres (bin): 1000100 I2C adres (hex): 0x44
Mounting Holes
I2C adres (bin): 1001001 I2C adres (hex): 0x49
I2C adres (bin): 1000001 I2C adres (hex): 0x41
Polarity protection
I2C adres (bin): 1000011 I2C adres (hexa): 0x4d

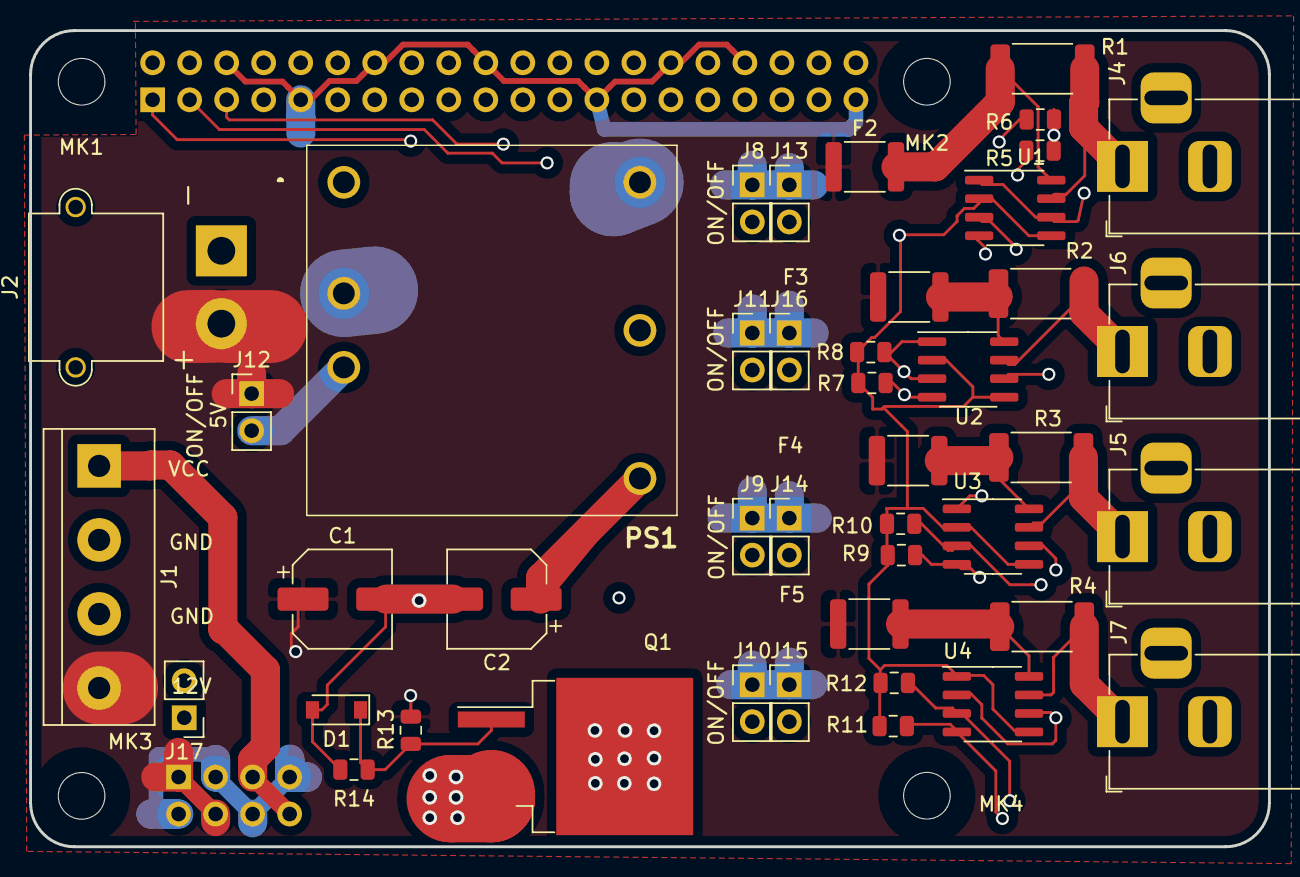
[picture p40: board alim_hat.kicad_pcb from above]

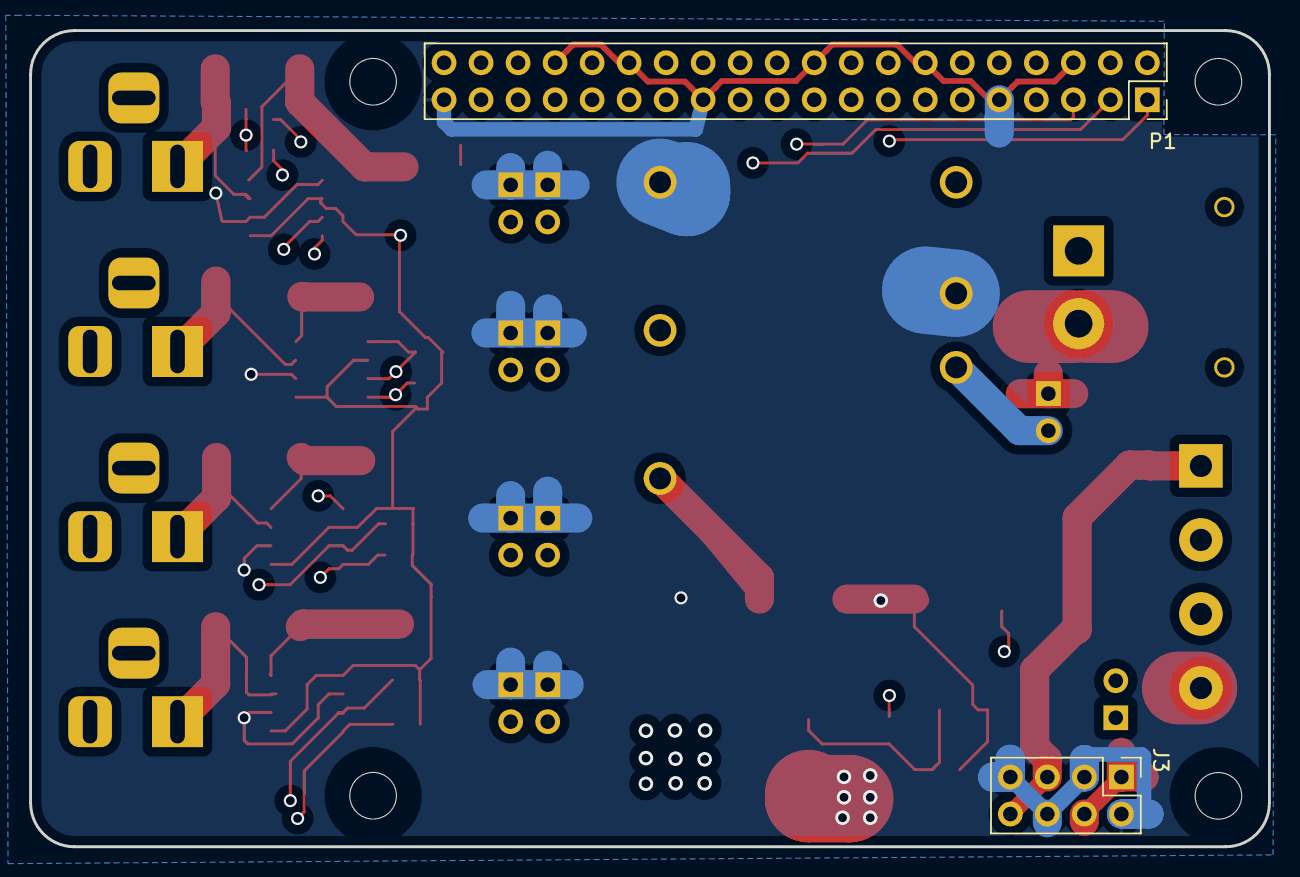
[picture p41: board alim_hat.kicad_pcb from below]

Board: 4 copper layers, 85.0 x 56.0 mm, 49 parts (2 on the bottom side), 22 nets.

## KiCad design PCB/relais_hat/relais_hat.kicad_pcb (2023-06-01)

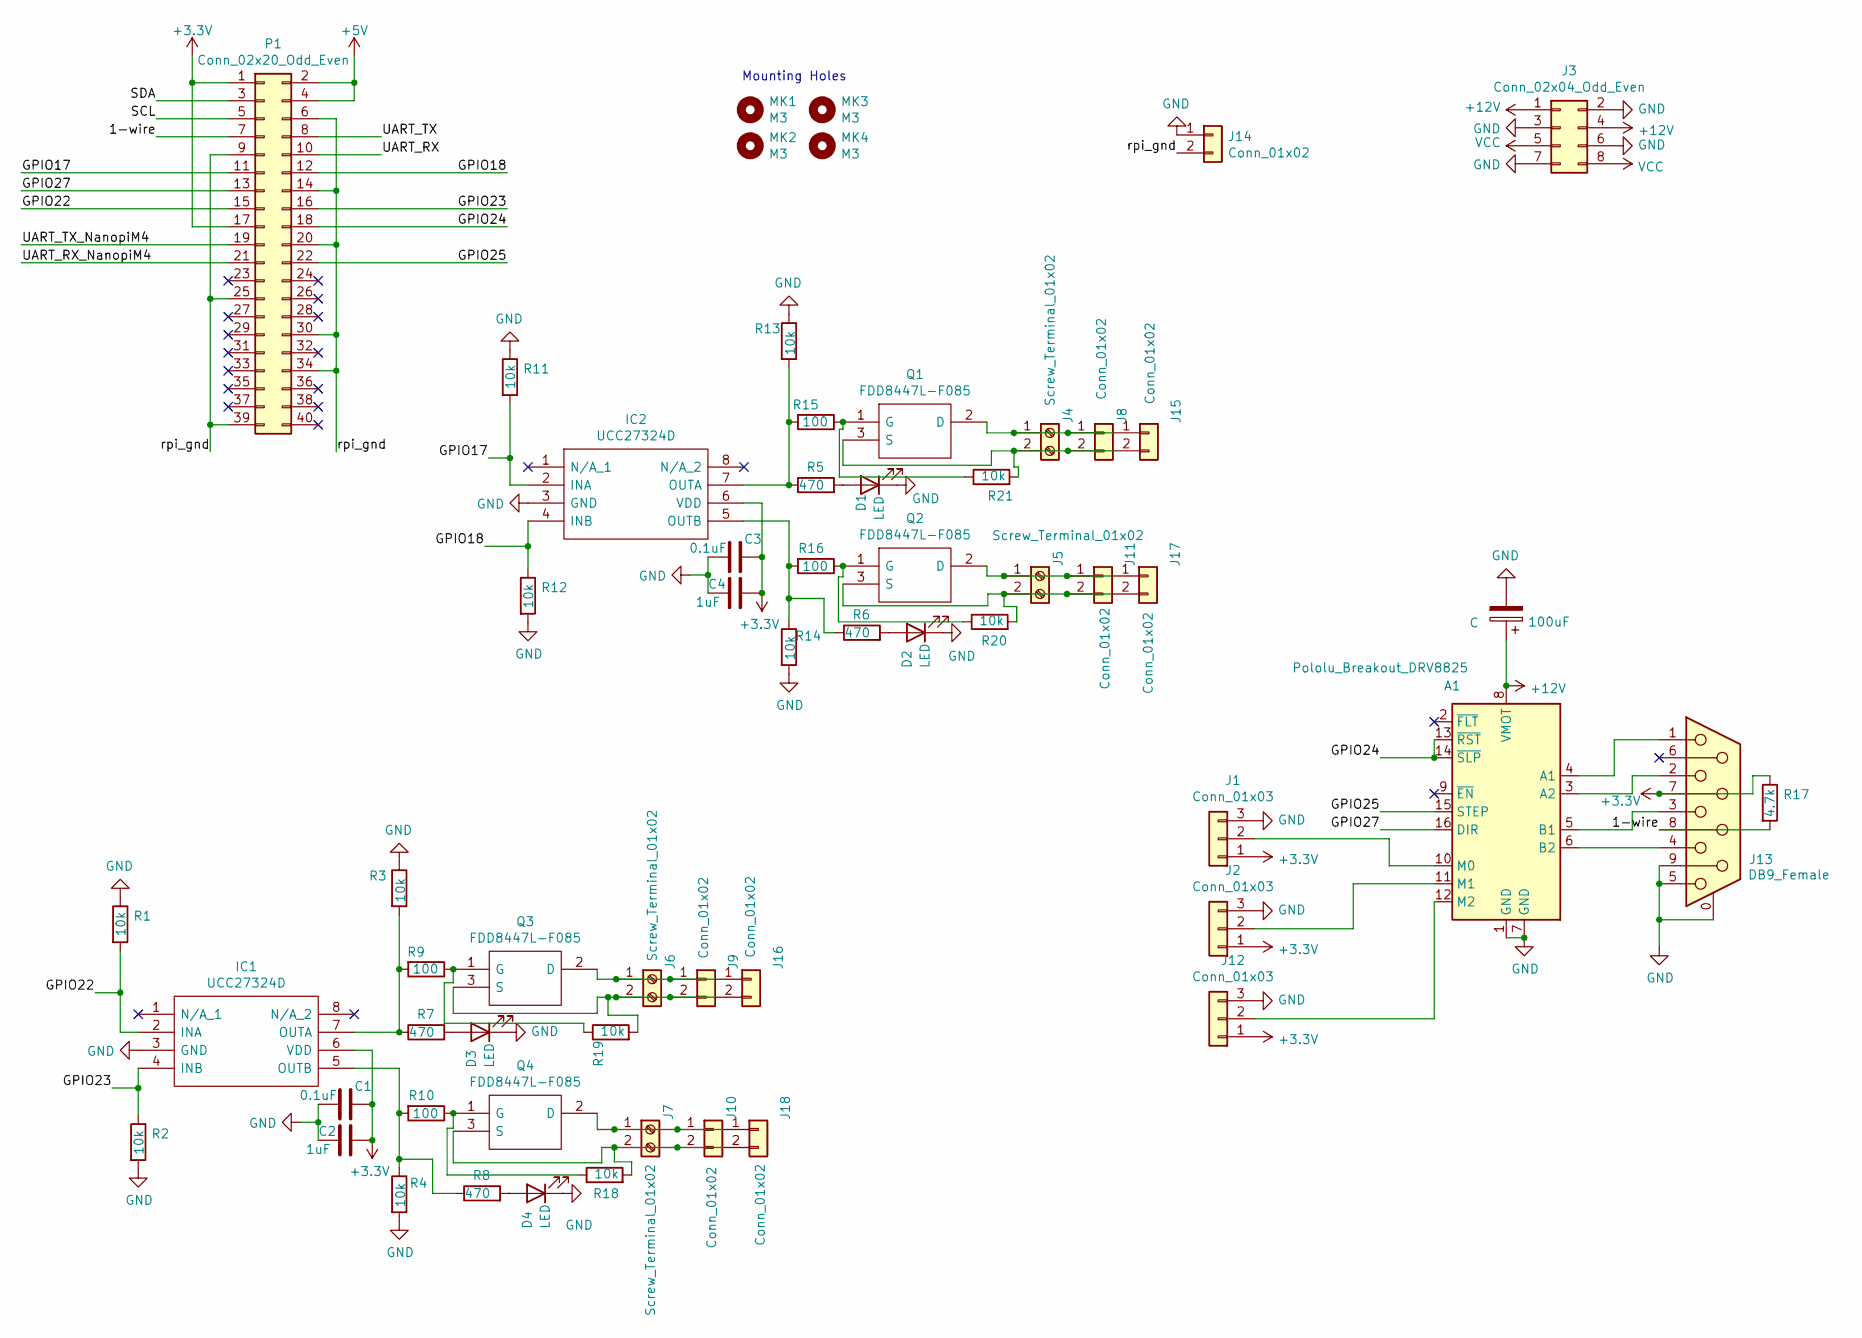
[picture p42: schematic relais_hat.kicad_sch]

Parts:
A1: Pololu_Breakout_DRV8825; Pololu_Breakout-16_15.2x20.3mm
C: 100uF; CP_Elec_6.3x7.7; LCSC C311622
C1, C3: 0.1uF; C_0805_2012Metric; LCSC C49678
C2, C4: 1uF; C_0805_2012Metric; LCSC C28323
D1, D2, D3, D4: LED; LED_0805_2012Metric; LCSC C84256
IC1, IC2: UCC27324D; SOIC127P600X175-8N; Mouser Part Number 595-UCC27324D
J1, J2, J12: Conn_01x03; PinHeader_1x03_P2.54mm_Vertical
J3: Conn_02x04_Odd_Even; PinHeader_2x04_P2.54mm_Vertical
J4, J5, J6, J7: Screw_Terminal_01x02; TerminalBlock_bornier-2_P5.08mm
J8, J9, J10, J11, J14, J15, J16, J17, J18: Conn_01x02; PinHeader_1x02_P2.54mm_Vertical
J13: DB9_Female; DSUB-9_Female_Horizontal_P2.77x2.84mm_EdgePinOffset4.94mm_H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
MK1, MK2, MK3, MK4: M3; MountingHole_2.7mm_M2.5
P1: Conn_02x20_Odd_Even; PinSocket_2x20_P2.54mm_Vertical
Q1, Q2, Q3, Q4: FDD8447L-F085; FDD8447LF085; Mouser Part Number 512-FDD8447L_F085
R1, R2, R3, R4, R11, R12, R13, R14, R18, R19, R20, R21: 10k; R_0805_2012Metric; LCSC C17414
R5, R6, R7, R8: 470; R_0805_2012Metric; LCSC C17710
R9, R15: 100; R_0805_2012Metric; LCSC C17414
R10, R16: 100; R_0805_2012Metric; LCSC C17408
R17: 4.7k; R_0805_2012Metric; LCSC C17673

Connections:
+3.3V: C1.1, C2.1, C3.1, C4.1, IC1.6 (VDD), IC2.6 (VDD), J1.1, J2.1, J12.1, J13.7, P1.1, P1.17, R17.1
+5V: P1.2, P1.4
+12V: A1.8 (VMOT), C.1, J3.1, J3.4
/1-wire: J13.8, P1.7, R17.2
/GPIO17: IC2.2 (INA), P1.11, R11.2
/GPIO18: IC2.4 (INB), P1.12, R12.1
/GPIO22: IC1.2 (INA), P1.15, R1.2
/GPIO23: IC1.4 (INB), P1.16, R2.1
/GPIO24: A1.13 (~RST), A1.14 (~SLP), P1.18
/GPIO25: A1.15 (STEP), P1.22
/GPIO27: A1.16 (DIR), P1.13
/SCL: P1.5
/SDA: P1.3
/UART_RX: P1.10
/UART_RX_NanopiM4: P1.21
/UART_TX: P1.8
/UART_TX_NanopiM4: P1.19
/rpi_gnd: J14.2, P1.6, P1.9, P1.14, P1.20, P1.25, P1.30, P1.34, P1.39
GND: A1.1 (GND), A1.7 (GND), C.2, C1.2, C2.2, C3.2, C4.2, D1.1 (K), D2.1 (K), D3.1 (K), D4.1 (K), IC1.3 (GND), IC2.3 (GND), J1.3, J2.3, J3.2, J3.3, J3.6, J3.7, J12.3, J13.0 (PAD), J13.5, J13.9, J14.1, R1.1, R2.2, R3.1, R4.2, R11.1, R12.2, R13.1, R14.2
unnamed: A1.4 (A1), J13.1
unnamed: A1.3 (A2), J13.2
unnamed: A1.5 (B1), J13.3
unnamed: A1.6 (B2), J13.4
unnamed: A1.10 (M0), J1.2
unnamed: A1.11 (M1), J2.2
unnamed: A1.12 (M2), J12.2
unnamed: D1.2 (A), R5.2
unnamed: D2.2 (A), R6.2
unnamed: D3.2 (A), R7.2
unnamed: D4.2 (A), R8.2
unnamed: IC1.7 (OUTA), R3.2, R7.1, R9.2
unnamed: IC1.5 (OUTB), R4.1, R8.1, R10.2
unnamed: IC2.7 (OUTA), R5.1, R13.2, R15.2
unnamed: IC2.5 (OUTB), R6.1, R14.1, R16.2
unnamed: J7.1, J10.1, J18.1, Q4.2 (D)
unnamed: J7.2, J10.2, J18.2, Q4.3 (S), R18.2
unnamed: J5.1, J11.1, J17.1, Q2.2 (D)
unnamed: J5.2, J11.2, J17.2, Q2.3 (S), R20.2
unnamed: J4.1, J8.1, J15.1, Q1.2 (D)
unnamed: J4.2, J8.2, J15.2, Q1.3 (S), R21.2
unnamed: J6.1, J9.1, J16.1, Q3.2 (D)
unnamed: J6.2, J9.2, J16.2, Q3.3 (S), R19.2
unnamed: Q1.1 (G), R15.1, R21.1
unnamed: Q2.1 (G), R16.1, R20.1
unnamed: Q3.1 (G), R9.1, R19.1
unnamed: Q4.1 (G), R10.1, R18.1
VCC: J3.5, J3.8

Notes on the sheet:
Mounting Holes

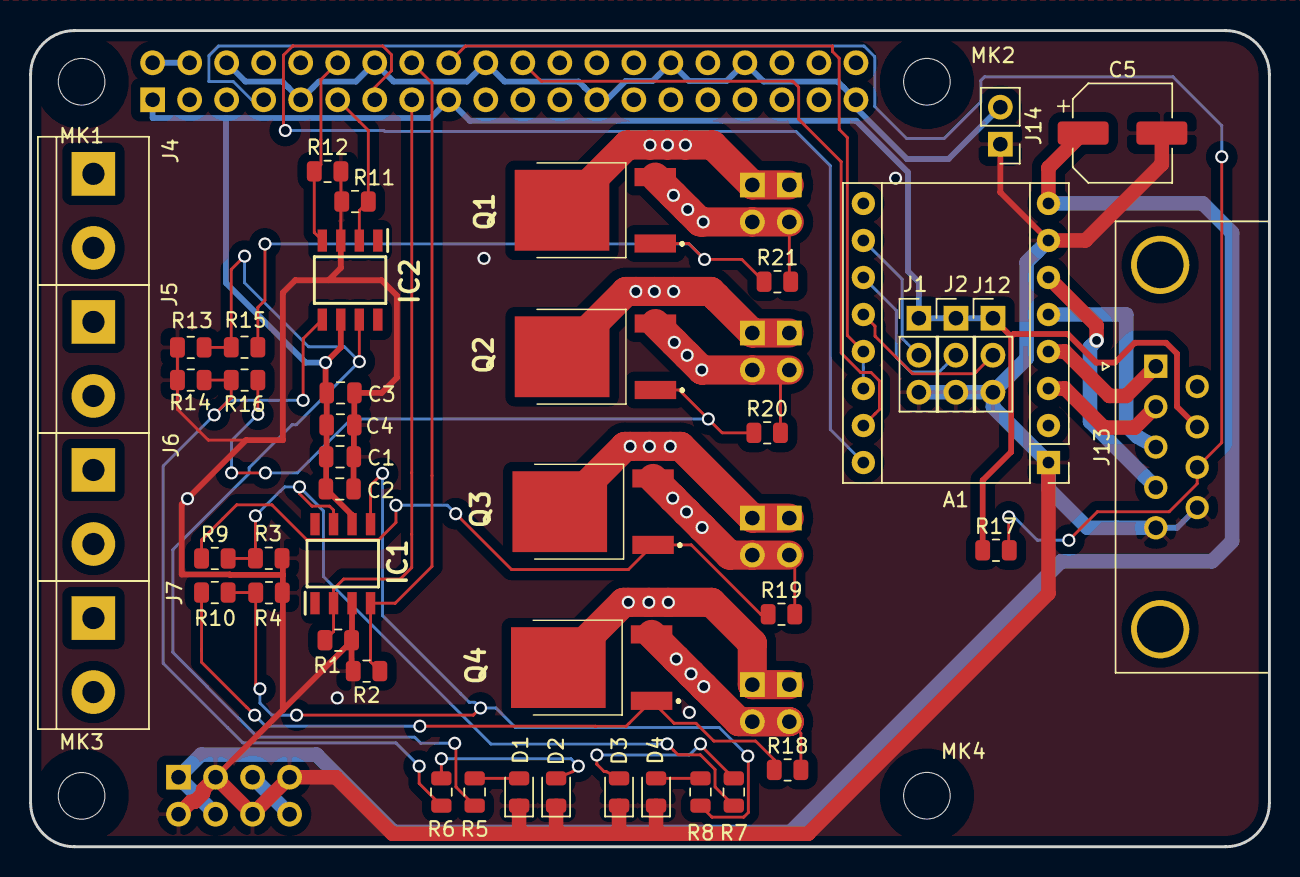
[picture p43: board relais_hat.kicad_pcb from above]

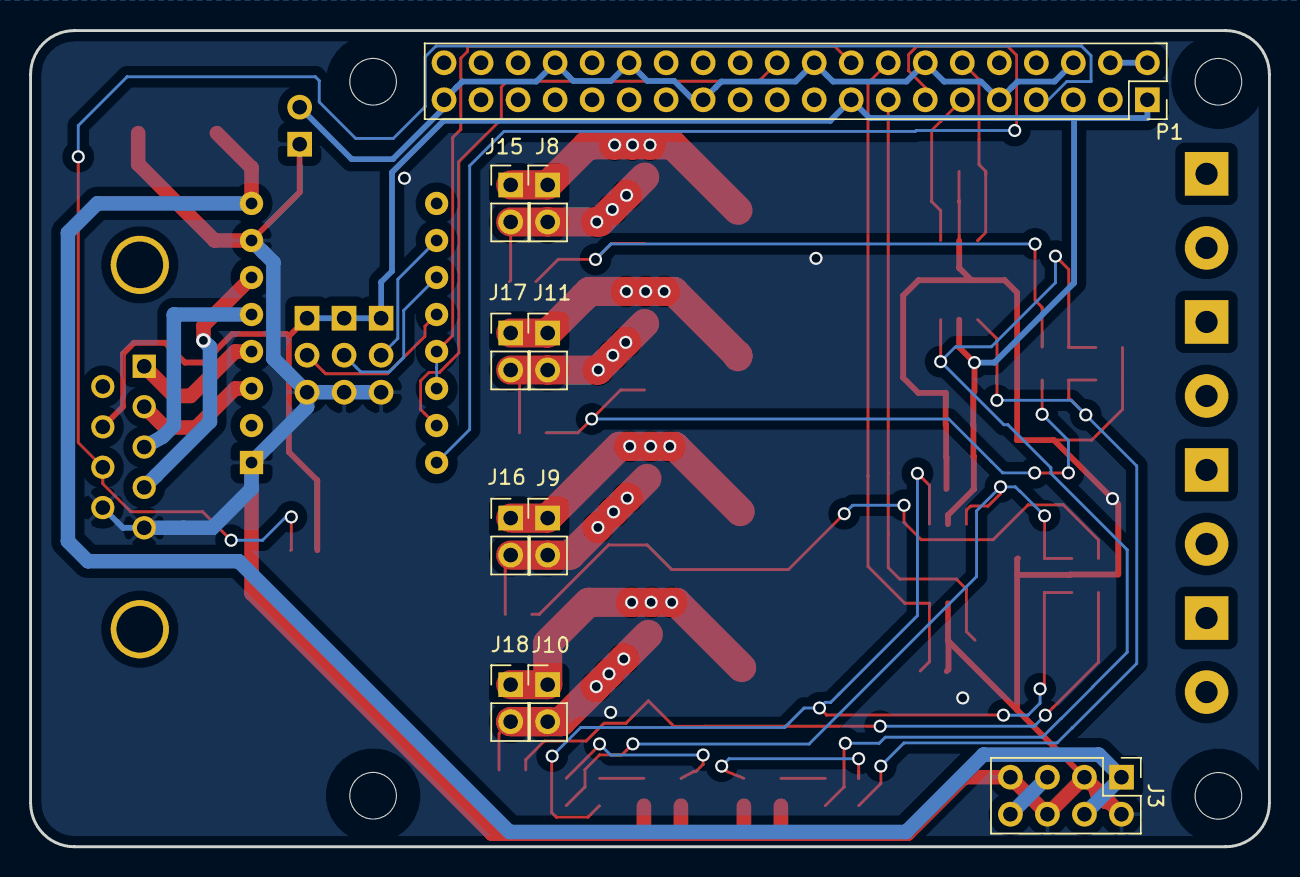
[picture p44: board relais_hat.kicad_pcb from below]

Board: 4 copper layers, 85.0 x 56.0 mm, 60 parts (10 on the bottom side), 41 nets.

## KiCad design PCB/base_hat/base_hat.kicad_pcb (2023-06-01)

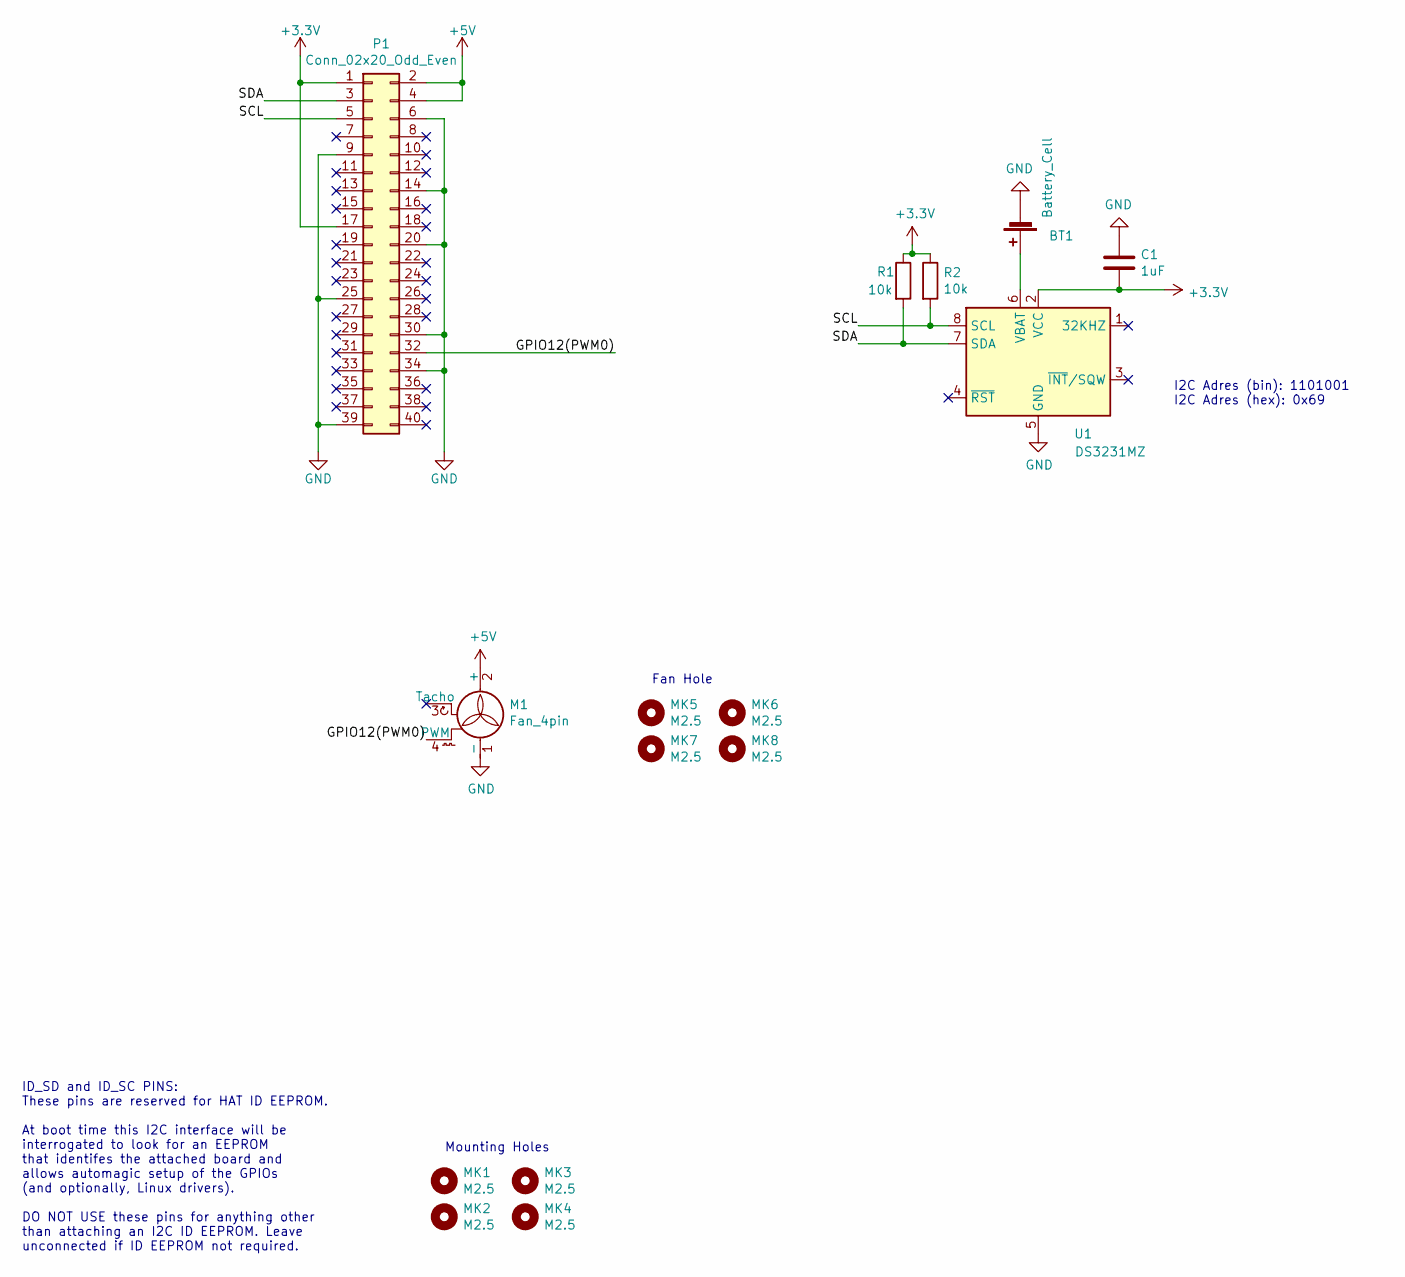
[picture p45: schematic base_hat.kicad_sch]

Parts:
BT1: Battery_Cell; BatteryHolder_Keystone_1060_1x2032; MF Part CR2032-BS-6-1; LCSC Part C70377
C1: 1uF; C_0805_2012Metric; MF Part 0805ZC105KAT2A; LCSC C179466
M1: Fan_4pin; PinHeader_1x04_P2.54mm_Vertical; MF Part 640456-4; LCSC Part C86504
MK1, MK2, MK3, MK4, MK5, MK6, MK7, MK8: M2.5; MountingHole_2.7mm_M2.5
P1: Conn_02x20_Odd_Even; PinSocket_2x20_P2.54mm_Vertical; MF Part C35165; LCSC Part C35165
R1, R2: 10k; R_0805_2012Metric; MF Part RT0805DRD0710KL; LCSC C17414
U1: DS3231MZ; SOIC-8_3.9x4.9mm_P1.27mm; MF Part DS3231MZ+TRL; LCSC C107410

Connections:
+3.3V: C1.2, P1.1, P1.17, R1.1, R2.1, U1.2 (VCC)
+5V: M1.2 (+), P1.2, P1.4
/GPIO12(PWM0): M1.4 (PWM), P1.32
/SCL: P1.5, R2.2, U1.8 (SCL)
/SDA: P1.3, R1.2, U1.7 (SDA)
GND: BT1.2 (-), C1.1, M1.1 (-), P1.6, P1.9, P1.14, P1.20, P1.25, P1.30, P1.34, P1.39, U1.5 (GND)
unnamed: BT1.1 (+), U1.6 (VBAT)

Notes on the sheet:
ID_SD and ID_SC PINS: These pins are reserved for HAT ID EEPROM. At boot time this I2C interface will be interrogated to look for an EEPROM that identifes the attached board and allows automagic setup of the GPIOs (and optionally, Linux drivers). DO NOT USE these pins for anything other than attach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
Fan Hole
Mounting Holes
I2C Adres (bin): 1101001 I2C Adres (hex): 0x69

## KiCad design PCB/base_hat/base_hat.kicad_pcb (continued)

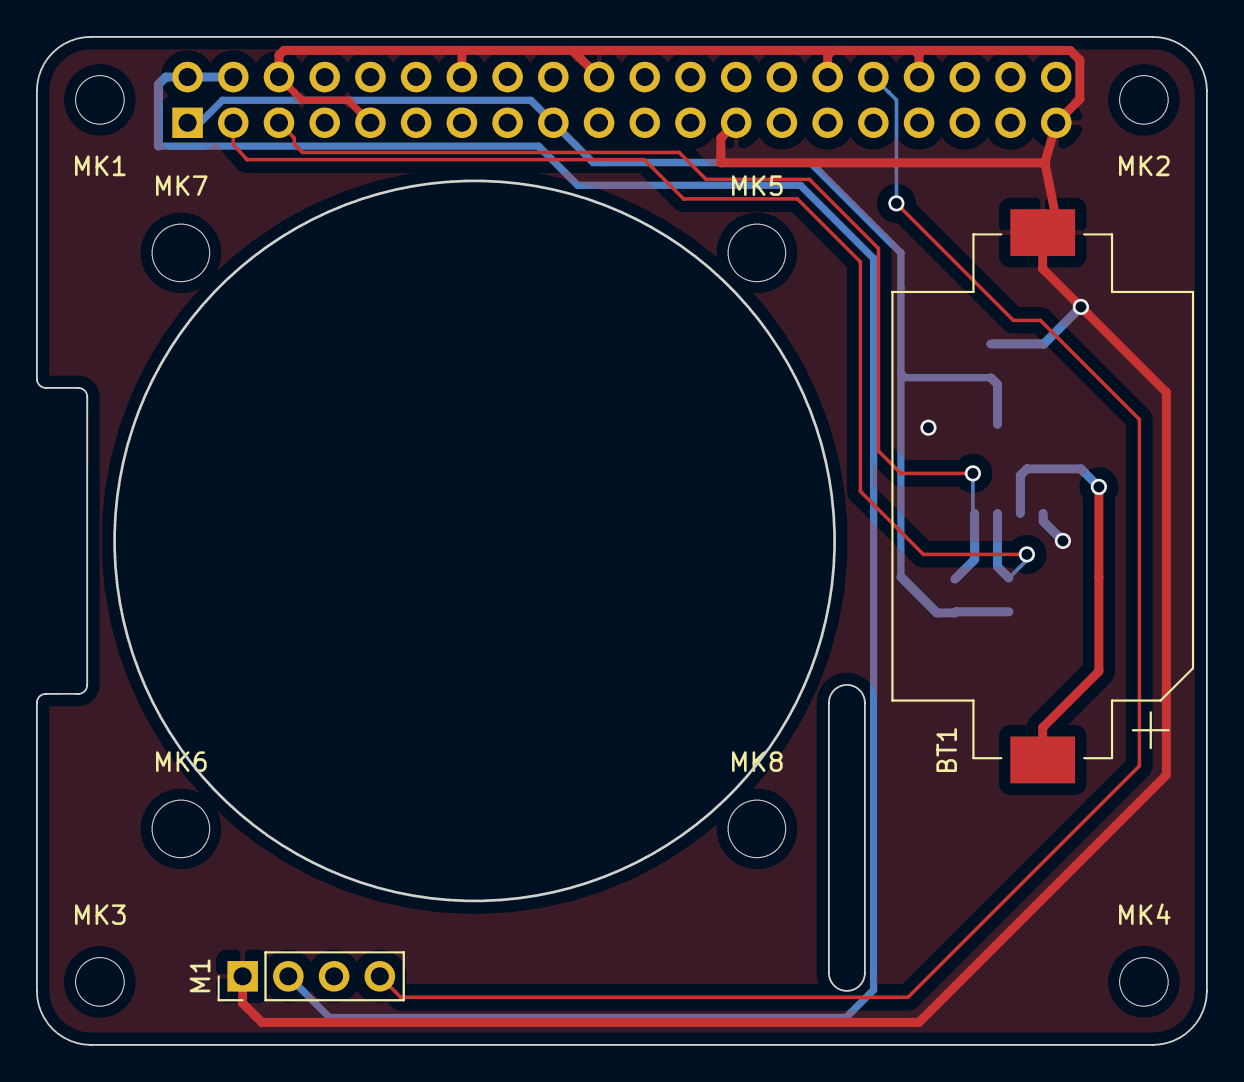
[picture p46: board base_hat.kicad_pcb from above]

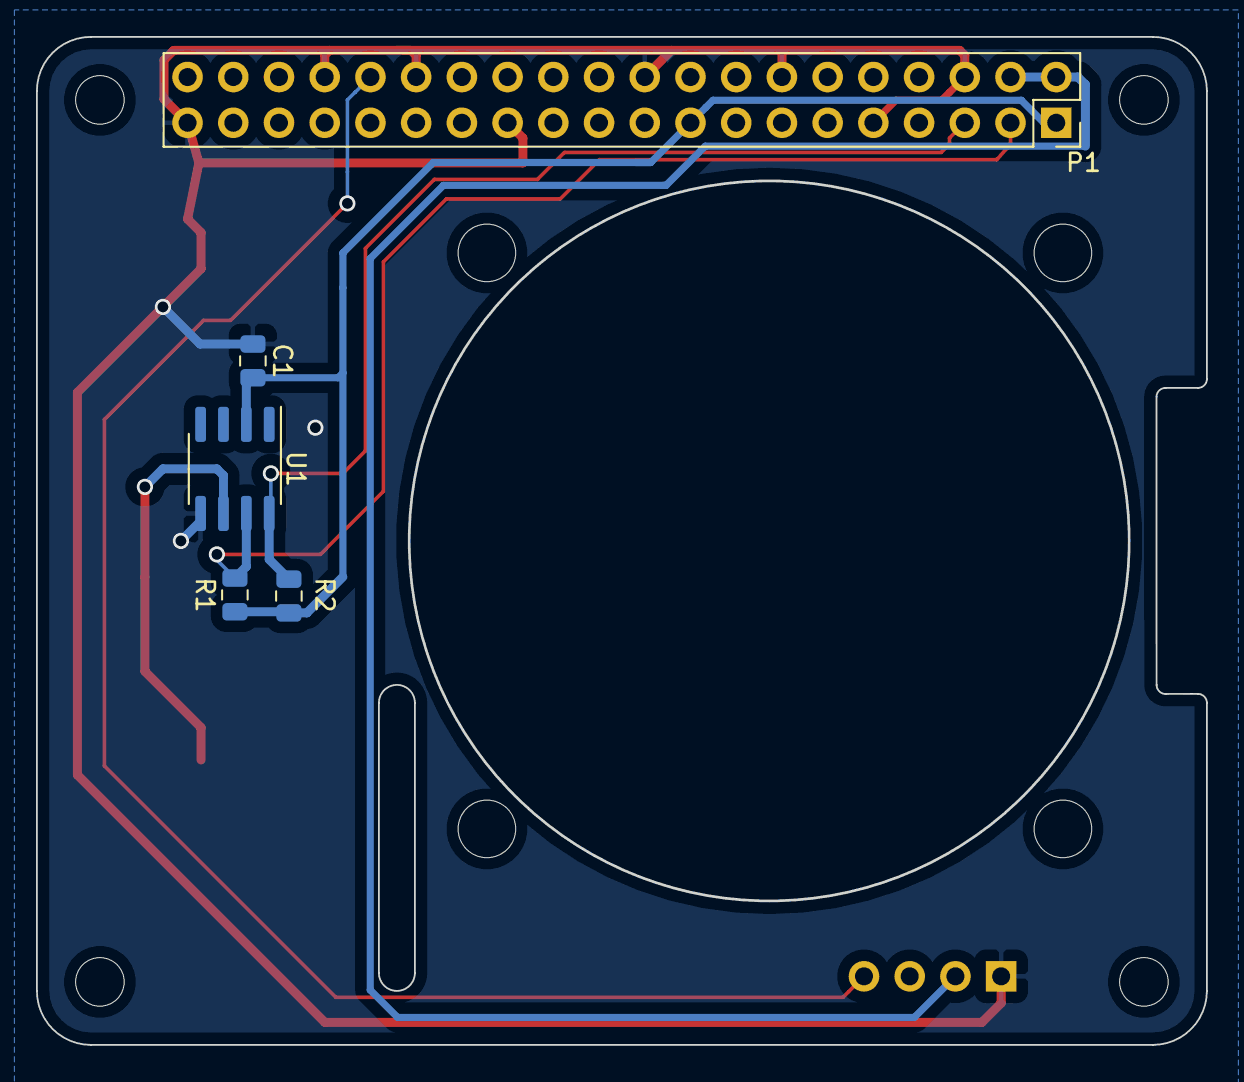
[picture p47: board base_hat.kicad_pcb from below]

Board: 2 copper layers, 65.0 x 56.0 mm, 15 parts (5 on the bottom side), 7 nets.

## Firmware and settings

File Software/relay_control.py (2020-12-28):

import os

gpio_out_1 = 0
gpio_out_2 = 1
gpio_out_3 = 3
gpio_out_4 = 4

bin_on = 1
bin_off = 0

def out_status(gpio_number,bin_stat):
    # ON=1 / OFF=0
    os.system('gpio mode '+str(gpio_number)+' out')
    os.system('gpio write '+str(gpio_number)+' '+str(bin_stat))

    return 1

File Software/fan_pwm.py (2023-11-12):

#!/usr/bin/python
# -*- coding: utf-8 -*-

import RPi.GPIO as GPIO
import time
import sys

# Configuration
FAN_PIN = 21  # BCM pin used to drive transistor's base
WAIT_TIME = 1  # [s] Time to wait between each refresh
FAN_MIN = 20  # [%] Fan minimum speed.
PWM_FREQ = 25  # [Hz] Change this value if fan has strange behavior

# Configurable temperature and fan speed steps
tempSteps = [50, 70]  # [°C]
speedSteps = [0, 100]  # [%]

# Fan speed will change only of the difference of temperature is higher than hysteresis
hyst = 1

# Setup GPIO pin
GPIO.setmode(GPIO.BCM)
GPIO.setup(FAN_PIN, GPIO.OUT, initial=GPIO.LOW)
fan = GPIO.PWM(FAN_PIN, PWM_FREQ)
fan.start(0)

i = 0
cpuTemp = 0
fanSpeed = 0
cpuTempOld = 0
fanSpeedOld = 0

# We must set a speed value for each temperature step
if len(speedSteps) != len(tempSteps):
    print("Numbers of temp steps and speed steps are different")
    exit(0)

try:
    while 1:
        # Read CPU temperature
        cpuTempFile = open("/sys/class/thermal/thermal_zone0/temp", "r")
        cpuTemp = float(cpuTempFile.read()) / 1000
        cpuTempFile.close()

        # Calculate desired fan speed
        if abs(cpuTemp - cpuTempOld) > hyst:
            # Below first value, fan will run at min speed.
            if cpuTemp < tempSteps[0]:
                fanSpeed = speedSteps[0]
            # Above last value, fan will run at max speed
            elif cpuTemp >= tempSteps[len(tempSteps) - 1]:
                fanSpeed = speedSteps[len(tempSteps) - 1]
            # If temperature is between 2 steps, fan speed is calculated by linear interpolation
            else:
                for i in range(0, len(tempSteps) - 1):
                    if (cpuTemp >= tempSteps[i]) and (cpuTemp < tempSteps[i + 1]):
                        fanSpeed = round((speedSteps[i + 1] - speedSteps[i])
                                         / (tempSteps[i + 1] - tempSteps[i])
                                         * (cpuTemp - tempSteps[i])
                                         + speedSteps[i], 1)
            
            file = open('/tmp/fanspeed.log', 'w')
            file.write(str(fanSpeed))
            file.close()
            if fanSpeed != fanSpeedOld:
                if (fanSpeed != fanSpeedOld
                        and (fanSpeed >= FAN_MIN or fanSpeed == 0)):
                    fan.ChangeDutyCycle(fanSpeed)
                    fanSpeedOld = fanSpeed
            cpuTempOld = cpuTemp

        # Wait until next refresh
        time.sleep(WAIT_TIME)


# If a keyboard interrupt occurs (ctrl + c), the GPIO is set to 0 and the program exits.
except KeyboardInterrupt:
    print("Fan ctrl interrupted by keyboard")
    GPIO.cleanup()
    sys.exit()

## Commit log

2020-08-03 remove gerber
    [base_hat-B_Cu.gbl, base_hat-B_Mask.gbs, base_hat-B_SilkS.gbo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]
2020-08-03 create 3 folder
    [2920L500_16MR.stp, Driver DRV8825.stp, INA219AIDR.stp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]
2020-08-03 change image position and change library to lib in res_hat
    [res_hat.kicad_pcb]
2020-08-04 update position off gps and optimise pcb
    [res_hat.kicad_pcb]
2020-08-28 clean file and genrate lastep pcb step/image/pdf
    [alim.sch, base_hat.csv, base_hat.xls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]
2020-08-28 add fab file for JLCPCB
    [BOM_JLCPCB.csv, POS_JLCPCB.csv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]
2020-08-28 upgrade alim piste size on alim board
    [alim_hat.kicad_pcb]
2020-08-30 add tab for futur BOM
    [composant.xlsx]
2020-09-01 add lcls part number and add Fab file
    [BOM_alim_hat_JLCPCB.csv, POS_alim_hat_JLCPCB.csv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]
2020-09-01 update/add LCSC ref and create fab file
    bug for Res_hat with JLCPCB site
    [BOM_base_hat_JLCPCB.csv, BOM_relais_hat_JLCPCB.csv, BOM_res_hat_JLCPCB.csv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]
2020-09-02 add res_hat fab file
    [BOM_res_hat_JLCPCB.csv, POS_res_hat_JLCPSB.csv, composant.xlsx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]
2020-09-03 correct wrong ref for JLCPCB
    [BOM_base_hat_JLCPCB.csv, BOM_relais_hat_JLCPCB.csv, relais_hat.sch]
2020-09-05 correct wring align for 4x2pin connector
    [res_hat-B_Adhes.gbr, res_hat-B_Cu.gbr, res_hat-B_Mask.gbr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]
2020-09-05 Add 3D models for printing
    [Carter Power.stp, Carter RPI4.stp, Carter ReS.stp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]
2020-09-22 warning : correct big error on alim hat
    [alim_hat-B_Cu.gbl, alim_hat-B_Mask.gbs, alim_hat-B_Paste.gbp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]
2020-09-22 change connector type
    [relais_hat.kicad_pcb]
2020-09-29 New revision
    Update +2mm over RPI fan hat
2020-09-29 New revision, and .stl files
    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
2020-09-29 Add Carter RPI
    [Carter RPI4.stp]
2020-09-29 Add .stl file of SD cover
    [Couvercle SD.stl]
2020-10-04 Q1/2/3/4 orientation correction
    [POS_relais_hat_JLCPCB.csv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]
2020-10-08 change led color for red
    [BOM_relais_hat_JLCPCB.csv]
2020-10-08 correct wrong R4/R12 position
    [POS_relais_hat_JLCPCB.csv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]
2020-10-12 add hexa i2c adress
    [alim_hat.sch, base_hat.sch, res_hat.sch]
2020-10-24 change DC for XT30, change controle res for pwm
    add ds1050Z-025+ change for xt30 connector for in alim
    [BOM_res_hat_JLCPCB.csv, POS_res_hat_JLCPSB.csv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]
2020-10-24 add serigraph and update name for componant
    [alim_hat.kicad_pcb, alim_hat.sch]
2020-10-24 add 3d model for xt30
    [alim_hat.kicad_pcb]
2020-10-25 complet new polarity protection
    update fab file
    [BOM_alim_hat_JLCPCB.csv, POS_alim_hat_JLCPCB.csv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]
2020-10-29 update alim and relais pcb 2-> 4 couches
    [alim_hat.kicad_pcb, alim_hat.sch, relais_hat.kicad_pcb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]
2020-10-29 update 3d model and fab file for all board
    [BOM_alim_hat_JLCPCB.csv, BOM_relais_hat_JLCPCB.csv, POS_alim_hat_JLCPCB.csv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]
2020-10-29 ajust skills for alim board
    [alim_hat-B_Cu.gbl, alim_hat-B_Mask.gbs, alim_hat-B_Paste.gbp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]
2020-10-30 ajust all board
    [BOM_alim_hat_JLCPCB.csv, BOM_relais_hat_JLCPCB.csv, BOM_res_hat_JLCPCB.csv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]
2020-10-30 add second trace for big fuse
    [POS_alim_hat_JLCPCB.csv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]
2020-10-30 update ref for relais hate
    [BOM_relais_hat_JLCPCB.csv, relais_hat.sch]
2020-11-13 ajust terminal position in relay board
    change hole diameter in res_board
    [relais_hat-B_Cu.gbl, relais_hat-B_Mask.gbs, relais_hat-B_Paste.gbp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]
2020-11-13 update terminal 3d
    [alim_hat.kicad_pcb, relais_hat.kicad_pcb]
2020-11-13 add jack dc for res-hate 3d modem
    [res_hat.kicad_pcb]
2020-11-13 Add new revison
    [Carter Power.stp, Carter RPI4.stp, Carter ReS.stp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]
2020-11-18 invert polarity xt30 connector
    [alim_hat-B_Cu.gbl, alim_hat-B_Mask.gbs, alim_hat-B_Paste.gbp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]
2020-12-27 change relay to mofset
    [BOM_relais_hat_JLCPCB.csv, POS_relais_hat_JLCPCB.csv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]
2020-12-27 add 3D xt30 model
    [BOM_relais_hat_JLCPCB.csv, POS_relais_hat_JLCPCB.csv, alim_hat.kicad_pcb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]
2020-12-27 add temp 1-wire in db9 connector
    [BOM_relais_hat_JLCPCB.csv, POS_relais_hat_JLCPCB.csv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]
2020-12-27 add relay shell instruction and correction for script+ina219
    remove wrong script
    [relay_control.py]
2020-12-28 add python prog for relay
2021-02-10 New revision
    change hole of the nut, the height of RPI's carter, the height of the cover, length of the SD cover
    [Carter Power.stl, Carter Power.stp, Carter RPI4.stp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]
2021-04-23 add R 10k on source/gate
    [BOM_relais_hat_JLCPCB.csv, POS_relais_hat_JLCPCB.csv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]
2021-04-23 change 12v to GND Jack DC cut-off
    [alim_hat-B_Cu.gbl, alim_hat-B_Mask.gbs, alim_hat-B_Paste.gbp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]
2021-04-26 add pin header for inject 5V in VCC
    [alim_hat.kicad_pcb, alim_hat.sch]
2021-04-27 correcte R100ohms ref on BOM
    [BOM_relais_hat_JLCPCB.csv, BOM_res_hat_JLCPCB.csv]
2021-04-28 Add mounting holes isolation
    [base_hat.kicad_pcb]
2021-04-28 Correct labels error of cross jumpers
    [res_hat.kicad_pcb]
2021-06-08 update gerber for alim hat
    [alim_hat-B_Cu.gbl, alim_hat-B_Mask.gbs, alim_hat-B_Paste.gbp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]
2021-06-08 Add BOM for other part alim_board
    [BOM_autre.xlsx]
2021-07-15 change trace for CP capa
    help jlcpcb analyse
    [alim_hat-B_Cu.gbl, alim_hat-B_Mask.gbs, alim_hat-B_Paste.gbp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]
2022-08-30 Update BOM_base_hat_JLCPCB.csv
    change capa for basic part
    [BOM_base_hat_JLCPCB.csv]
2023-06-01 upgrade res hat to kicad 7.0
    [res_hat.kicad_pcb, res_hat.kicad_sch]
2023-06-01 update base hat to Kicad 7.0
    [base_hat.kicad_sch]
2023-06-01 upgarde alim hat to kicad 7.0
    [alim_hat.kicad_sch]
2023-06-01 upgrade relais hat and all hat to kicad 7.0
    [alim_hat.kicad_pcb, base_hat.kicad_pcb, relais_hat.kicad_pcb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]
2023-11-12 add fan speed log
